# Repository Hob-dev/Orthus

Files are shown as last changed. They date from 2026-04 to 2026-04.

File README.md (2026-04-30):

# Orthus

An ergonomic split keyboard PCB with an integrated capacitive trackpad, Sharp Memory Display, and speaker. Designed around Kailh Choc low-profile switches and styled after Nothing.

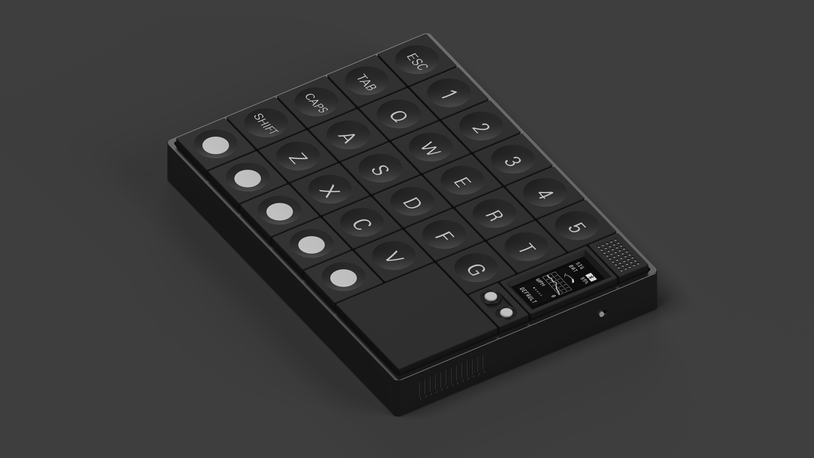
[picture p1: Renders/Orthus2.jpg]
Orthus iso render


## Overview

Orthus is a 6×5 ortholinear split — two mirrored halves, one with the alpha cluster (`QWERT`/`ASDFG`/`ZXCV`) and a number row (`1`–`5`), the other with the right-hand alphas, symbols, and a numpad row. Each half carries:

- 30 Kailh Choc keys (5 columns × 5 rows of alpha + outer modifier column + bottom-row arrow/macro circles)
- An integrated **OrthusTrackpad** capacitive sensor zone
- A **Sharp Memory Display** for live status (signal, battery, WPM, layer)
- Two side encoders / buttons next to the display
- A speaker grille

Both halves side-by-side:

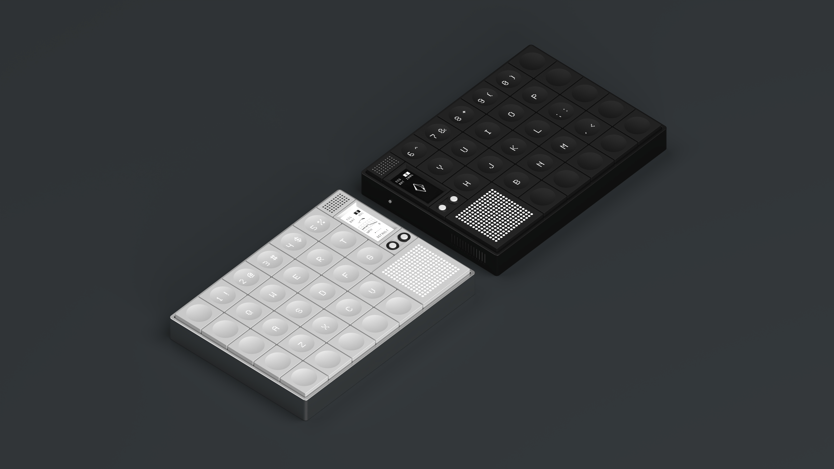
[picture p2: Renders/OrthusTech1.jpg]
Orthus split — both halves


Top-down view:

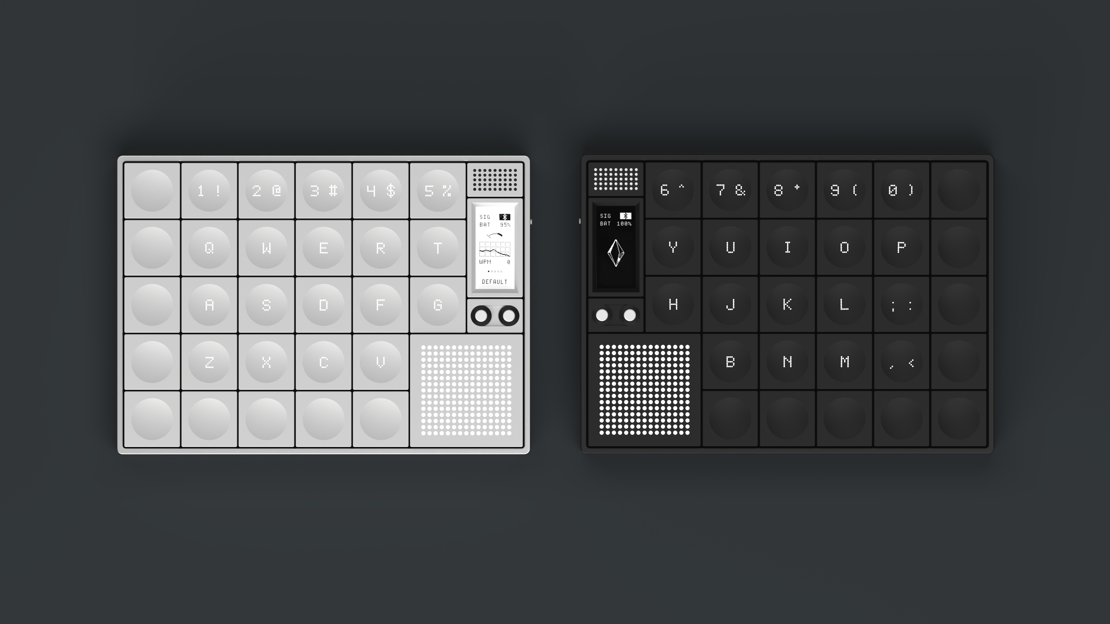
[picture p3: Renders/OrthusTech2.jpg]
Orthus top-down


## Status

**Functionally complete** — finishing touches remain before fabrication (see "Known gaps" below).

## Folder layout

```
Orthus/
├── KiCad/              Main KiCad 7+ project — open Orthus.kicad_pro
│   ├── Orthus.kicad_pcb        Main board layout
│   ├── Orthus.kicad_sch        Top-level schematic (loads sub-sheets)
│   ├── Left.kicad_sch          Left-half hierarchical sheet
│   ├── Right.kicad_sch         Right-half hierarchical sheet
│   ├── LeftMatrix.kicad_sch    Switch matrix sub-sheet
│   ├── OLED.kicad_sch          Display sub-sheet
│   ├── led.kicad_sch / led_r.kicad_sch   LED sub-sheets
│   ├── font/                   Custom silkscreen font SVGs (digits 0–9)
│   └── backups/                Dated KiCad auto-backups
├── Renders/            Project renders, layout studies, and WIP photos
├── 3D/                 Mechanical models — case, keycaps, trackpad
│   ├── Orthus.step / .stl / .gltf / .bin     Full assembly
│   ├── OrthusSimple*.step                    Simplified assembly variants
│   ├── OrthusKeycap*.step                    Keycap variants (Alt, TLBR, TRBL)
│   ├── AltarCap v2/v3.step                   Sculpted altar-style keycaps
│   ├── OrthusTrackpad*.step                  Trackpad PCB models
│   └── TM040YDHG32.step                      LCD reference model
├── Fabrication/        Trackpad grill cutouts (.dxf / .svg, square + slotted)
├── JLCPCB/             Empty — gerbers for the main PCB not yet generated
└── Components/
    ├── OrthusTrackpad/    Capacitive trackpad PCB (self-contained KiCad project + gerbers)
    └── OrthusSharp/       Sharp Memory Display breakout (KiCad project + gerbers)
```

## Components

| Component | Purpose | Status |
|---|---|---|
| **OrthusTrackpad** | Custom mutual-capacitance trackpad PCB integrated into each half. Self-contained KiCad project with its own JLCPCB gerber output. | Complete |
| **OrthusSharp** | Sharp Memory Display breakout, derived from an open-source `sharp_memory_display` design and significantly modified. KiCad 5 originals preserved under `Components/OrthusSharp/Legacy/`. | Complete |
| **OrthusMouseWheel** | Scroll wheel module — *not included in this repo, still under `Custom/Ergomania/OrthusMouseWheel/`.* | Unfinished |

## Alternative Renders

| | |
|---|---|
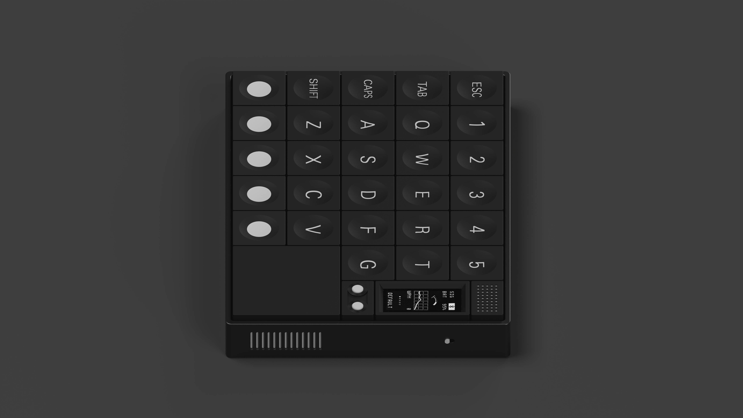
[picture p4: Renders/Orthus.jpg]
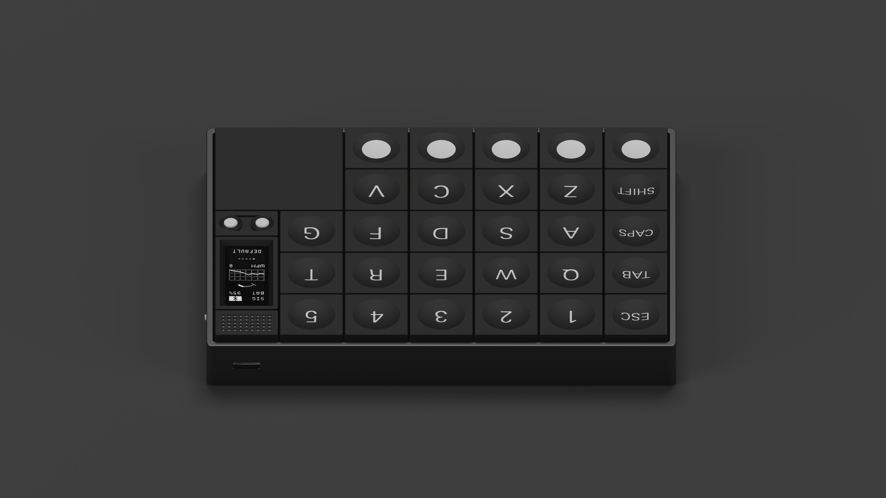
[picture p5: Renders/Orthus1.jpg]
|  |  |
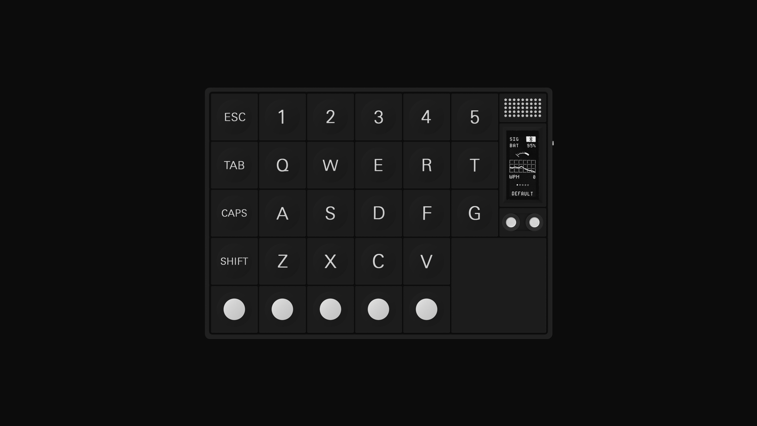
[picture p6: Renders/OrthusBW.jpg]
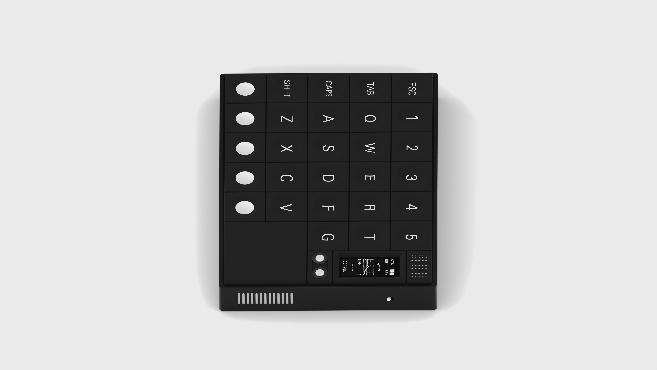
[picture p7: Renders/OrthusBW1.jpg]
|  |  |
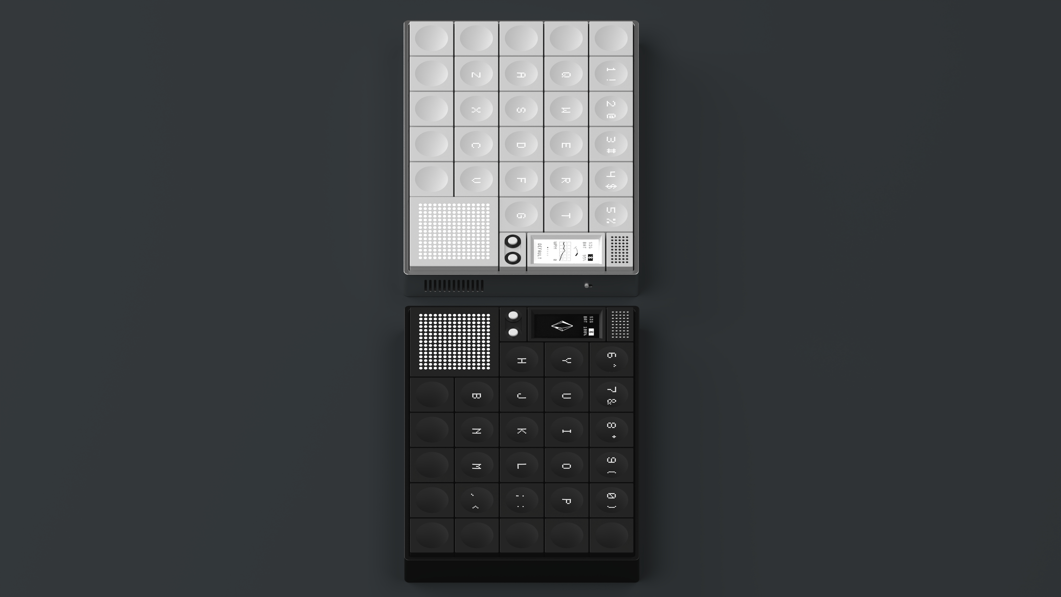
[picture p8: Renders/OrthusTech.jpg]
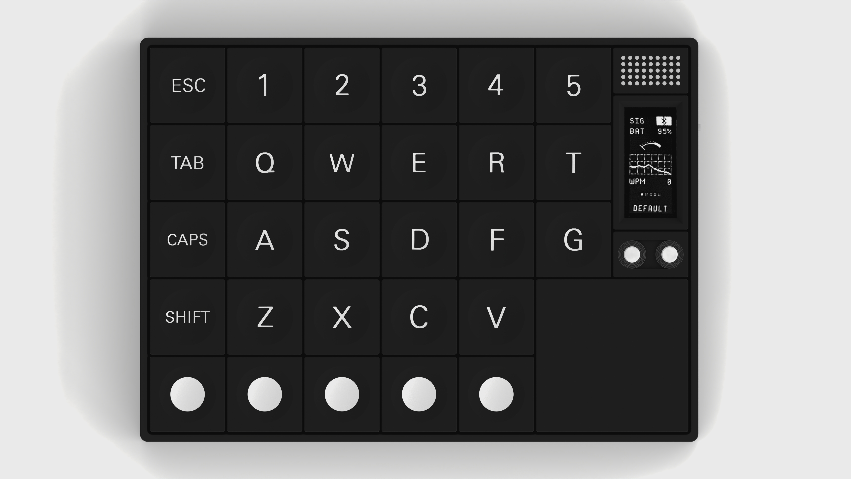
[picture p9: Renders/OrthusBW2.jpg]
|  |  |
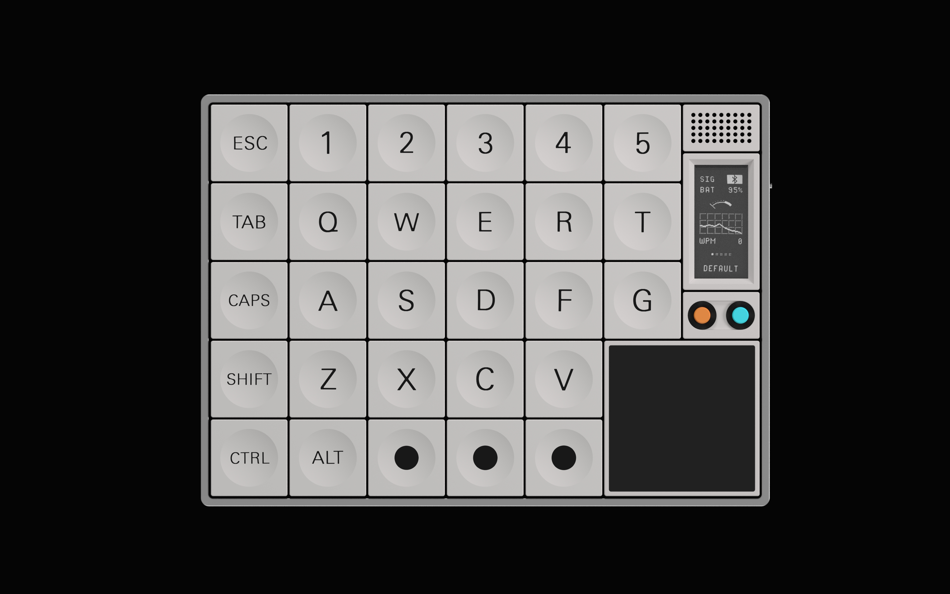
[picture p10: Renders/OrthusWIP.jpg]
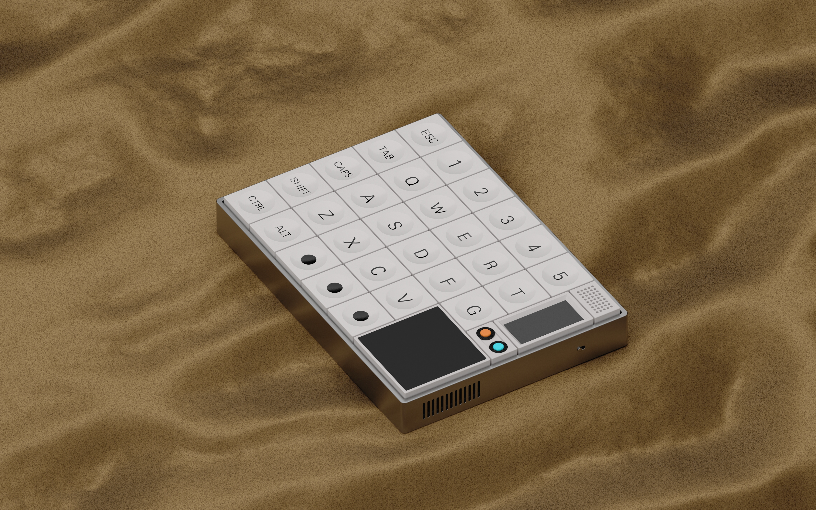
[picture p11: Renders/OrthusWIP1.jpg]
|  |  |

Layout studies and design exploration:

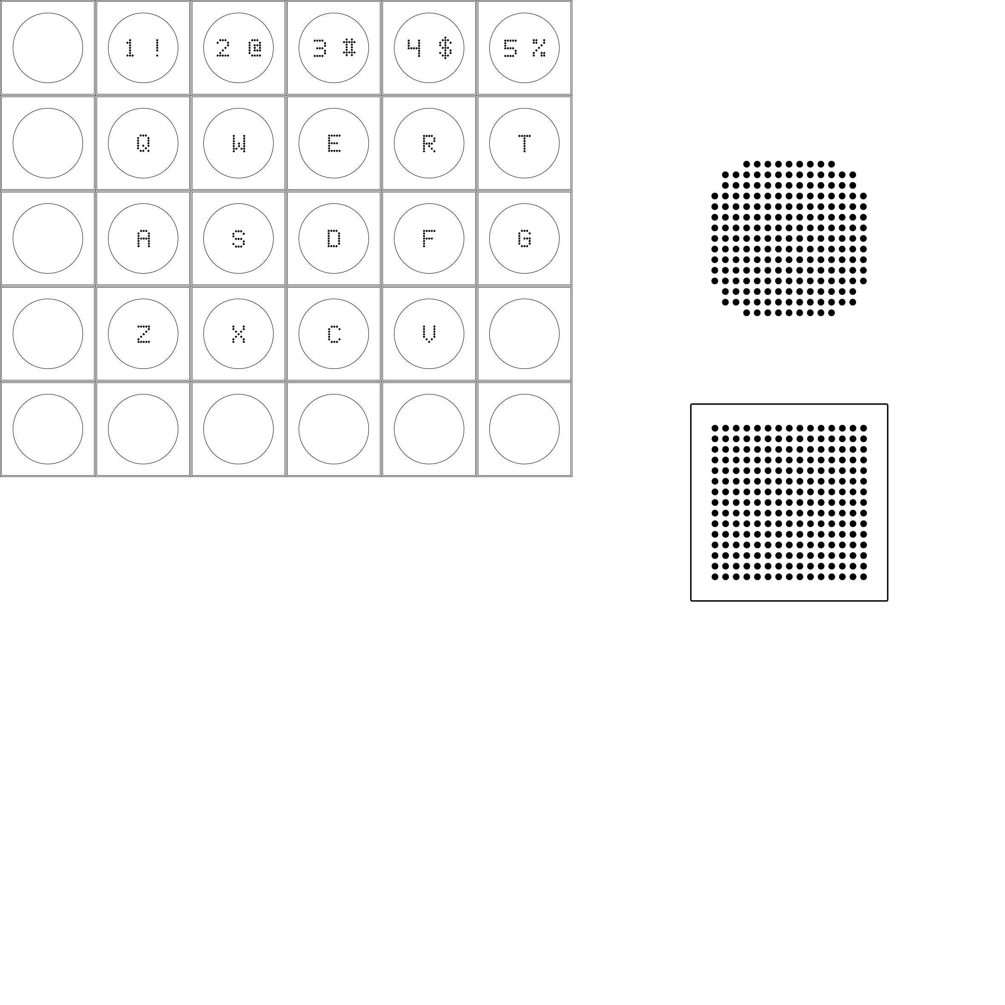
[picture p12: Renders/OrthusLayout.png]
Orthus layout study


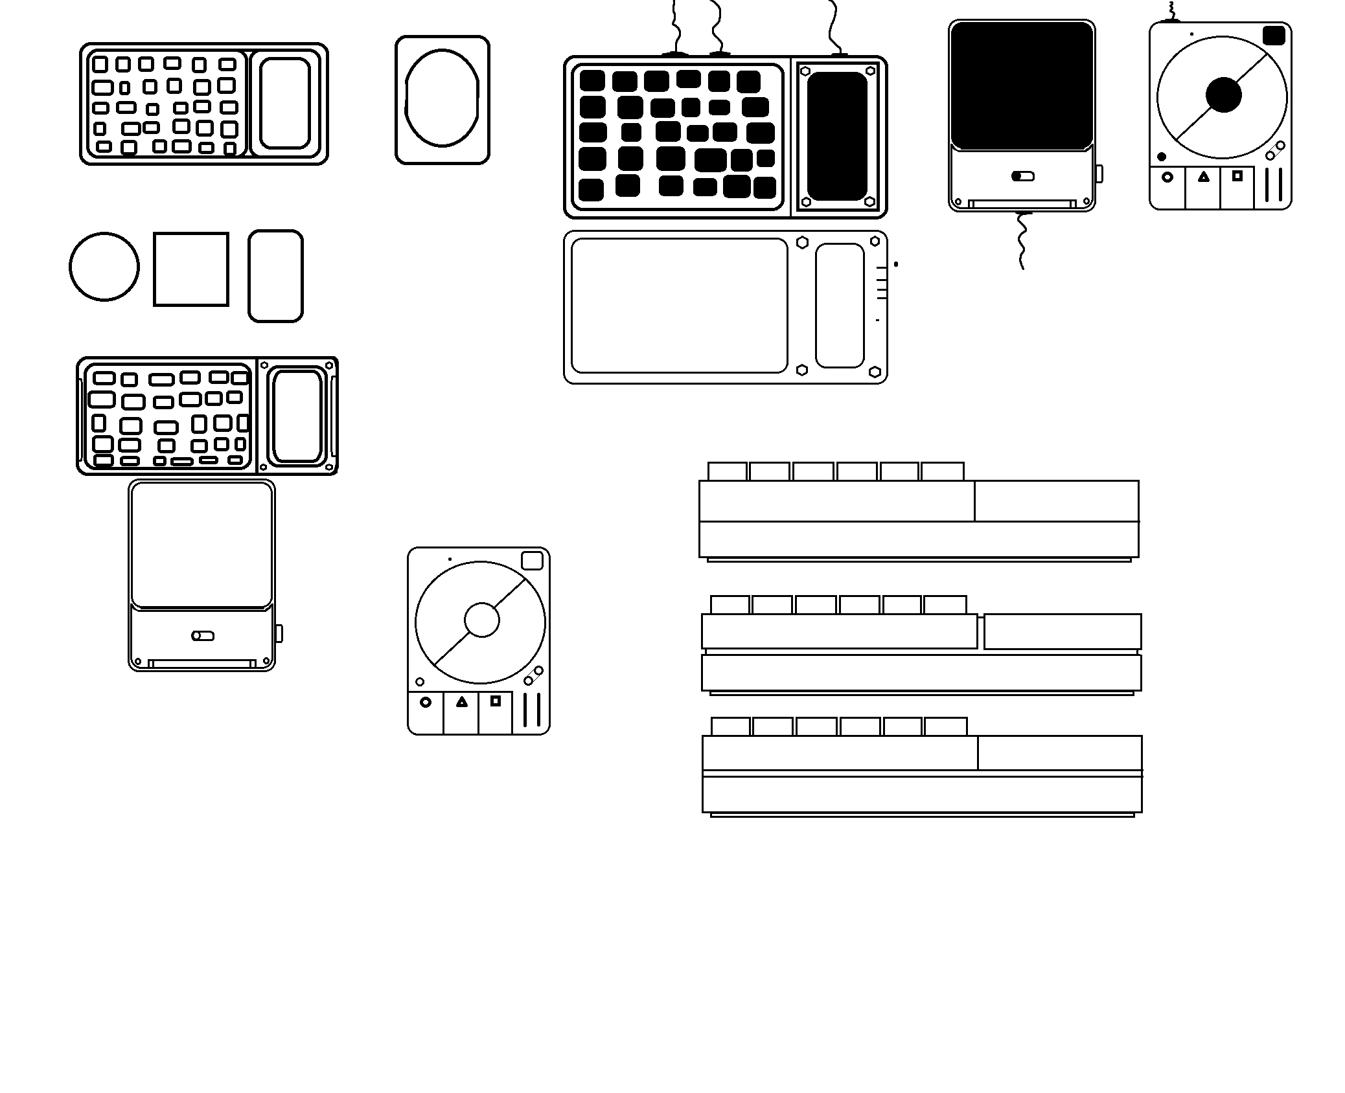
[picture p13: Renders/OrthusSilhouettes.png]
Form factor silhouettes


## Known gaps

- **No gerbers / JLCPCB order files** for the main Orthus PCB. `JLCPCB/` is an empty placeholder — gerbers need to be generated before fabrication.
- **No BOM / pick-and-place files** for the main PCB.
- **No assembly documentation** — refer to the hierarchical schematics under `KiCad/`.
- **3D model paths in `Orthus.kicad_pcb`** still reference absolute paths under `E:/EverythingKB/Custom/Ergomania/OrthusChoc/...`. The 3D viewer works locally because of this; for an open-source release these should be repointed at `Orthus/3D/`.
- **3D model path in `OrthusSharp.kicad_pro`** uses `../../Custom/Ergomania/test/OrthusSharp.step` (relative to its old location).
- **OrthusSharp `fp-lib-table`** carries hardcoded macOS paths (`/Users/karnadi/...`) inherited from the upstream fork — regenerate or repoint to your local KiCad libraries on first open.

## Attribution

`Components/OrthusSharp/` is derived from an open-source Sharp Memory Display breakout (see `Components/OrthusSharp/LICENSE`). Heavily modified for integration with Orthus.

## License

Orthus is licensed under the [Creative Commons Attribution-NonCommercial 4.0 International License (CC BY-NC 4.0)](https://creativecommons.org/licenses/by-nc/4.0/).

`Components/OrthusSharp/` is third-party and retains its original license — see [`Components/OrthusSharp/LICENSE`](Components/OrthusSharp/LICENSE).

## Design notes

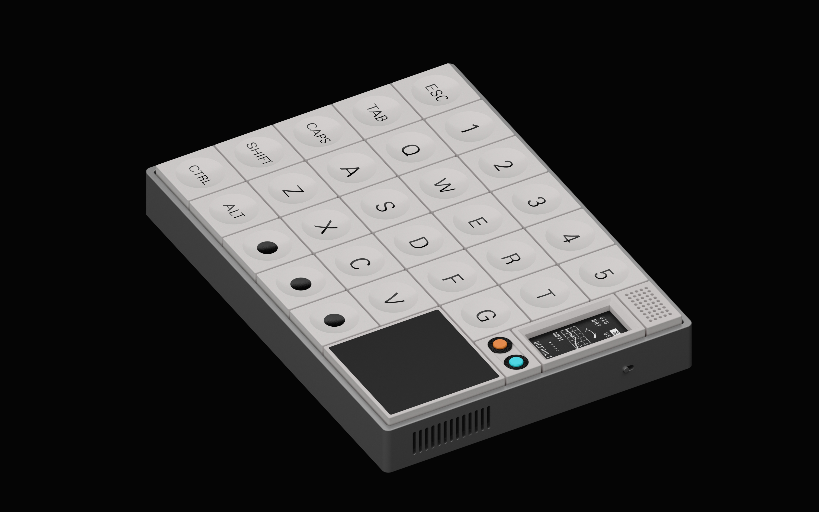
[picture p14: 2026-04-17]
Renders/OrthusWIP2.jpg

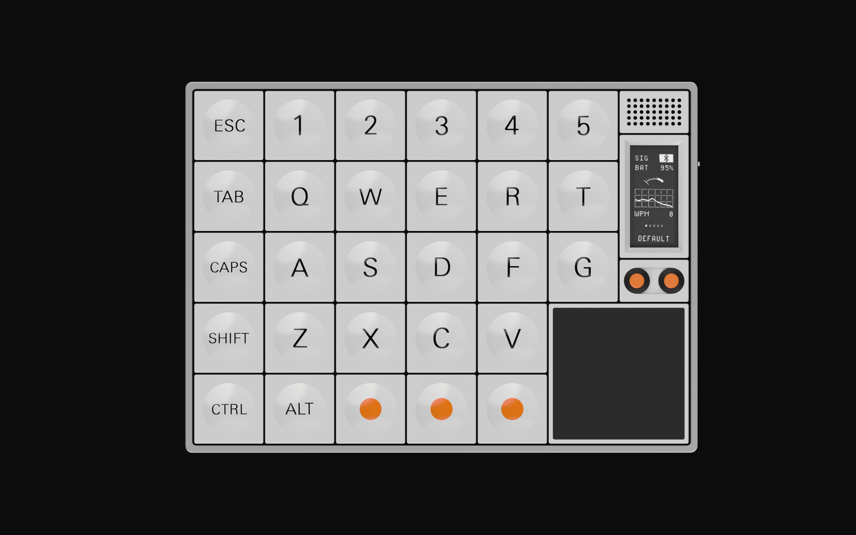
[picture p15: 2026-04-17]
Renders/OrthusWIP6.jpg

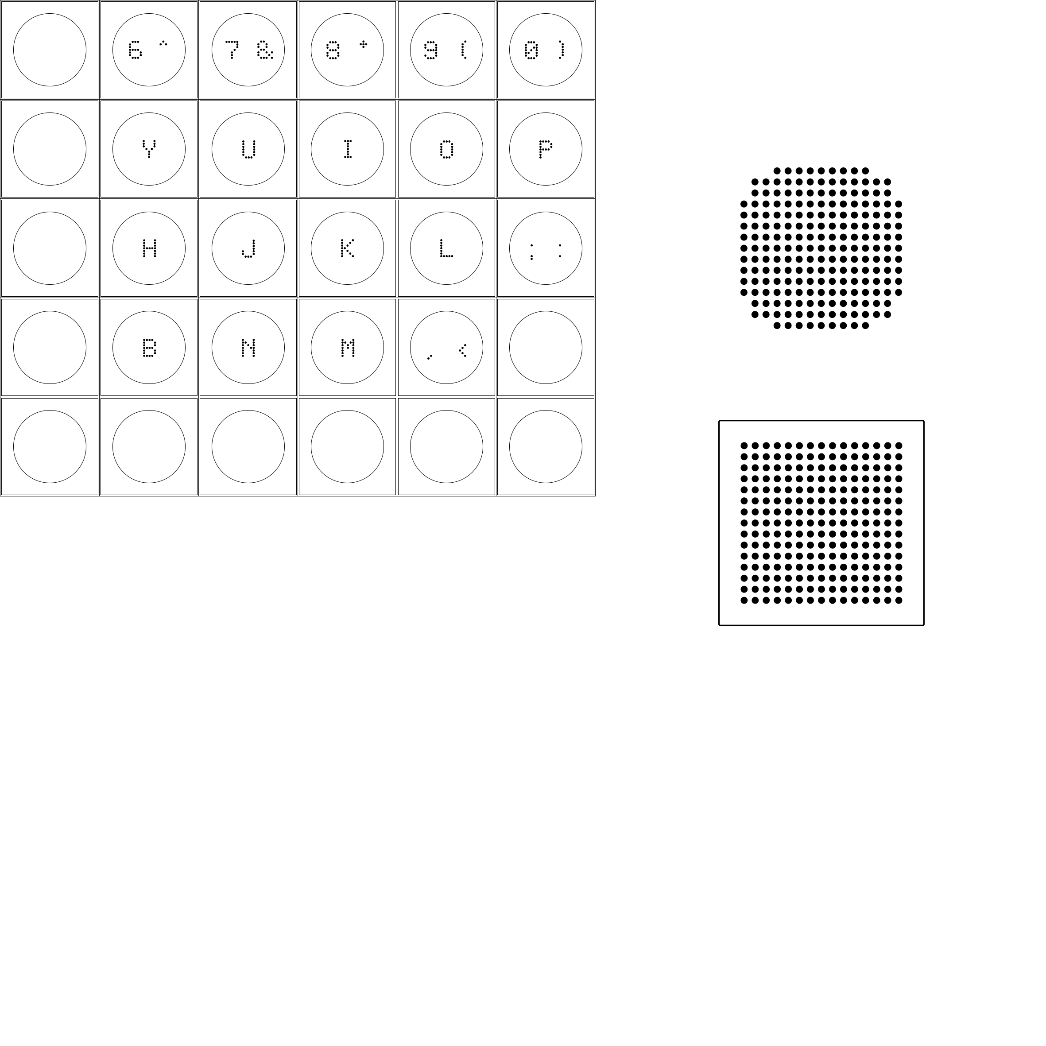
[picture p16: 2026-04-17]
Renders/OrthusLayout1.png

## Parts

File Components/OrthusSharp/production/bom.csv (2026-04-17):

Comment | Designator | Footprint | LCSC Part #
560pF/680pF Unpolarized capacitor, small symbol | C1 | C_0603_1608Metric_Pad1.08x0.95mm_HandSolder | C84721
1uF Unpolarized capacitor, small symbol | C2 | C_0603_1608Metric_Pad1.08x0.95mm_HandSolder | C15849
1uF Unpolarized capacitor, small symbol | C3 | C_0603_1608Metric_Pad1.08x0.95mm_HandSolder | C15849
Ferrite_Bead_Small | FB1,FB2 | R_0805_2012Metric_Pad1.20x1.40mm_HandSolder | C1017
MountingHole Mounting Hole without connection | H1,H2,H3,H4 | MountingHole_2.2mm_M2_DIN965_Pad
Conn_01x05 Generic connector, single row, 01x05, script generated (kicad-library-utils/schlib/autogen/connector/) | J1 | PinSocket_1x05_P2.54mm_Vertical
Conn_01x10 Generic connector, single row, 01x10, script generated (kicad-library-utils/schlib/autogen/connector/) | J2,J4 | Hirose_FH12-10S-0.5SH_1x10-1MP_P0.50mm_Horizontal | C506791
Conn_01x05_Male Generic connector, single row, 01x05, script generated (kicad-library-utils/schlib/autogen/connector/) | J3 | JST_SH_SM05B-SRSS-TB_1x05-1MP_P1.00mm_Horizontal
10k Resistor, small symbol | R1,R2,R3 | R_0603_1608Metric_Pad0.98x0.95mm_HandSolder | C25804

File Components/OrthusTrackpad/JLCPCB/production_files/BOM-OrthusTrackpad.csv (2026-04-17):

Comment | Designator | Footprint | LCSC | Quantity
100nF | C7 | C_0402_1005Metric | C1525 | 1
100pF | C1,C3,C5 | C_0402_1005Metric | C1546 | 3
IQS7211E001QNR | U1 | UQFN-20_L3.0-W3.0-P0.40-BL-EP1.7 | C20179547 | 1
4.7k | R1,R2,R3 | R_0603_1608Metric | C23162 | 3
Conn_01x06 | J1 | FPC-SMD_6P-P0.50_XUNPU_FPC-05F-6PH15 | C2856814 | 1
2.2uF | C2,C4,C6 | C_0402_1005Metric | C60078 | 3

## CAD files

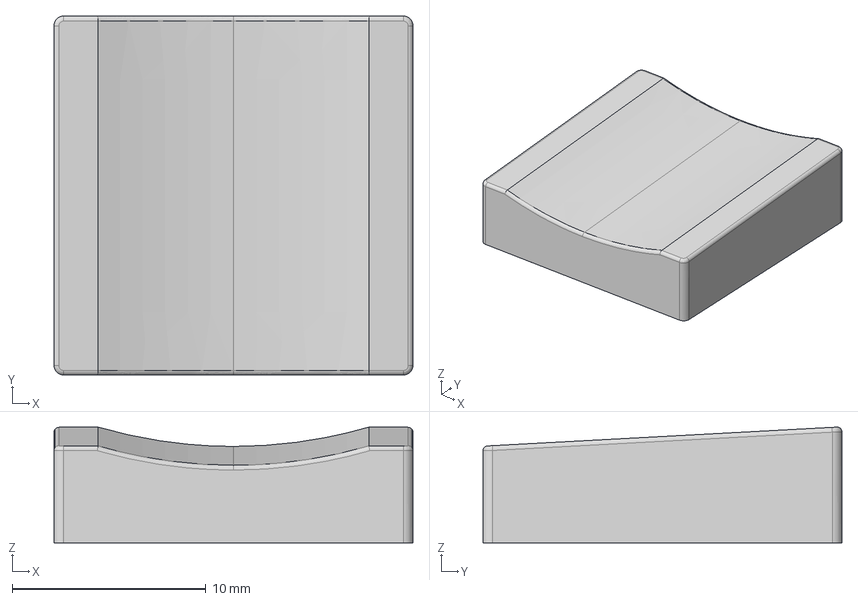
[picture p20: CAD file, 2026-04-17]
3D/OrthusKeycapAlt.step
18.5 x 18.5 x 5.99 mm

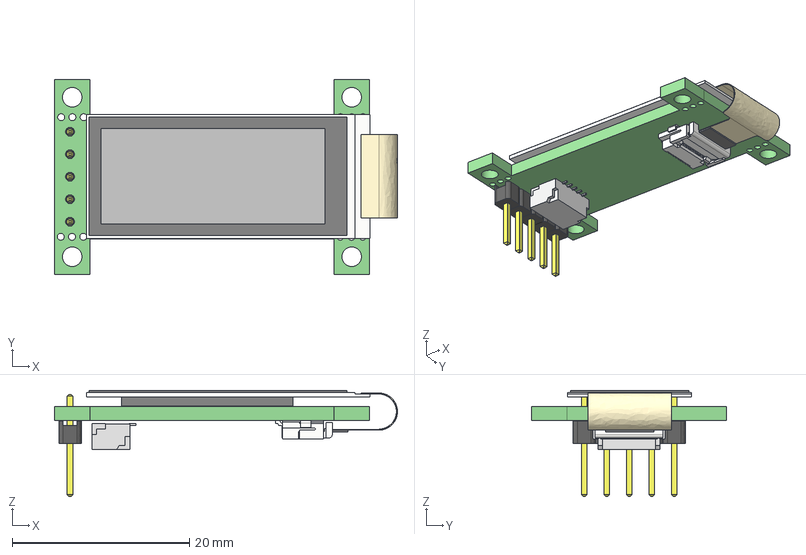
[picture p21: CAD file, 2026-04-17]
Components/OrthusSharp/OrthusSharp.step
38.7 x 22.0 x 12.0 mm
sharp_memory_display PCB

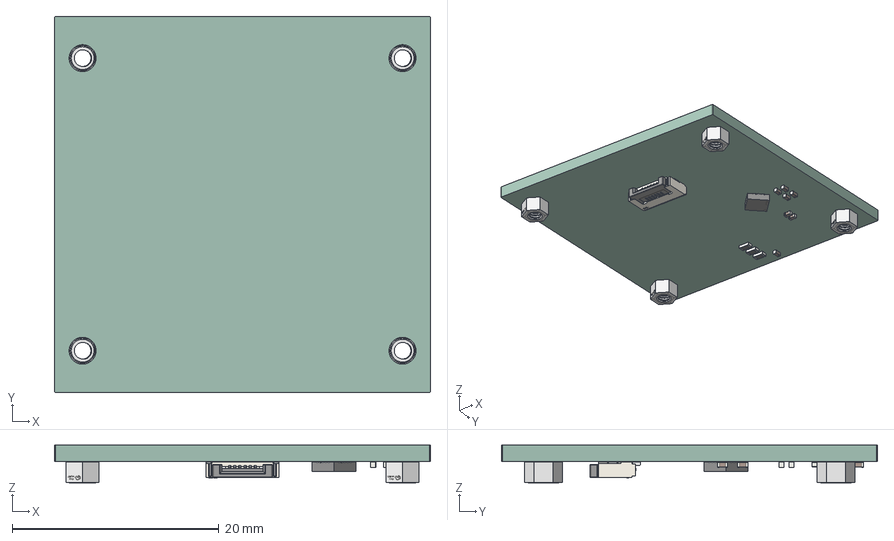
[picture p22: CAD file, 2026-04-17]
Components/OrthusTrackpad/3D/OrthusTrackpad.step
36.4 x 36.4 x 3.65 mm
C_0402_1005Metric x 7
SMD-1_SMTSO1620MTJ x 4
R_0603_1608Metric x 3
UQFN-20_L3.0-W3.0-P0.40-BL-EP1.7
FPC-SMD_6P-P0.50_XUNPU_FPC-05F-6PH15
OrthusTrackpad_PCB

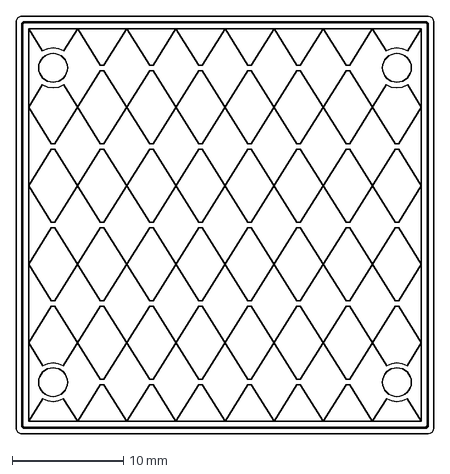
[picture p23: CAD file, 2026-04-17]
Components/OrthusTrackpad/Fabrication/MutualCapSensorGride.dxf
37.6 x 37.6 mm

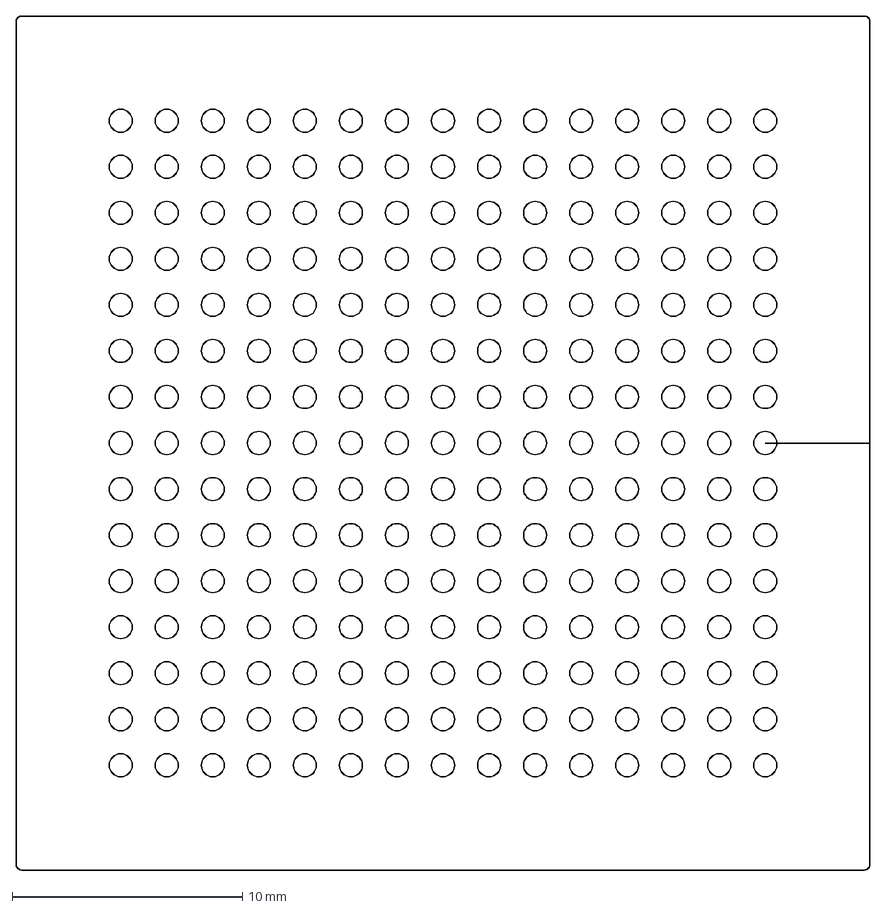
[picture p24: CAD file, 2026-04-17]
Fabrication/TrackpradGrillsSquare.dxf
37.1 x 37.1 mm

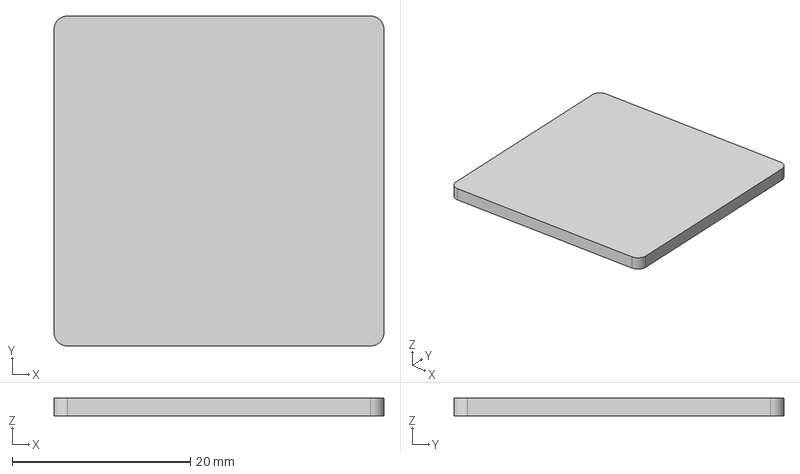
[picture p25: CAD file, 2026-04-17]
3D/OrthusTrackpad3D.step
37.0 x 37.0 x 2.00 mm

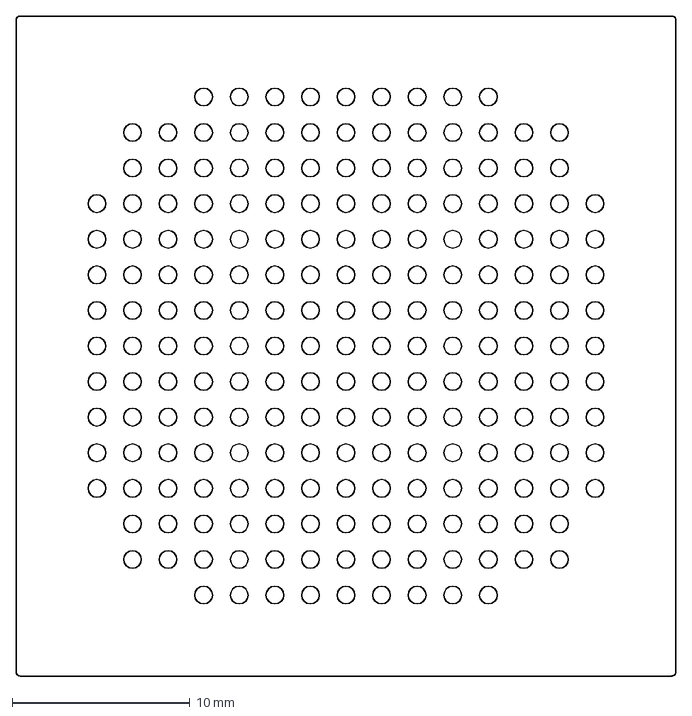
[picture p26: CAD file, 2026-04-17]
Fabrication/TrackpradGrills.dxf
37.1 x 37.1 mm

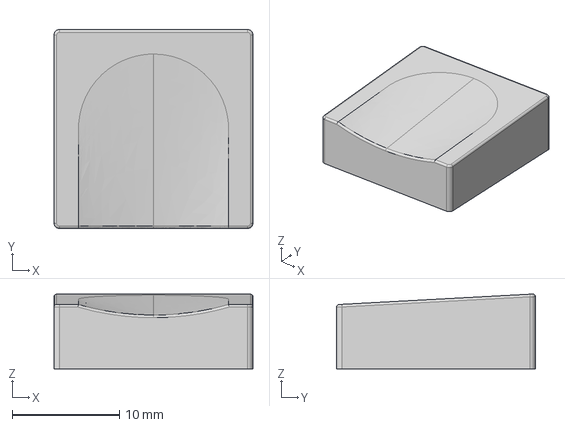
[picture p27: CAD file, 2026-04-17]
3D/OrthusKeycapAlt1.step
18.5 x 18.5 x 6.99 mm

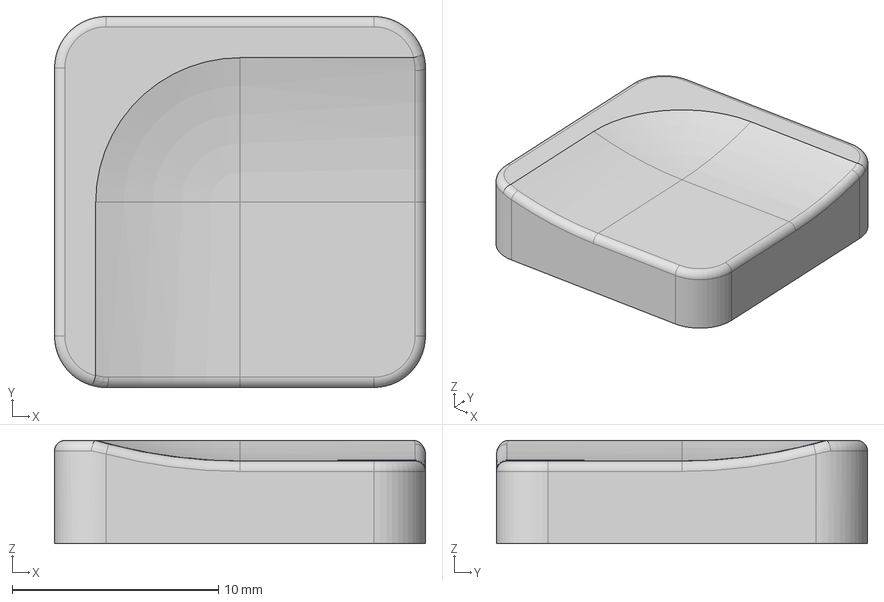
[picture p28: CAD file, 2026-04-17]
3D/OrthusKeycapAltTLBR.step
18.0 x 18.0 x 5.00 mm

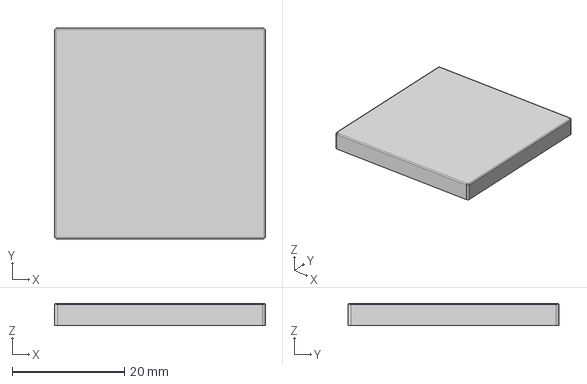
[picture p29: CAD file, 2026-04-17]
3D/OrthusTrackpad v31.step
37.6 x 37.6 x 4.00 mm

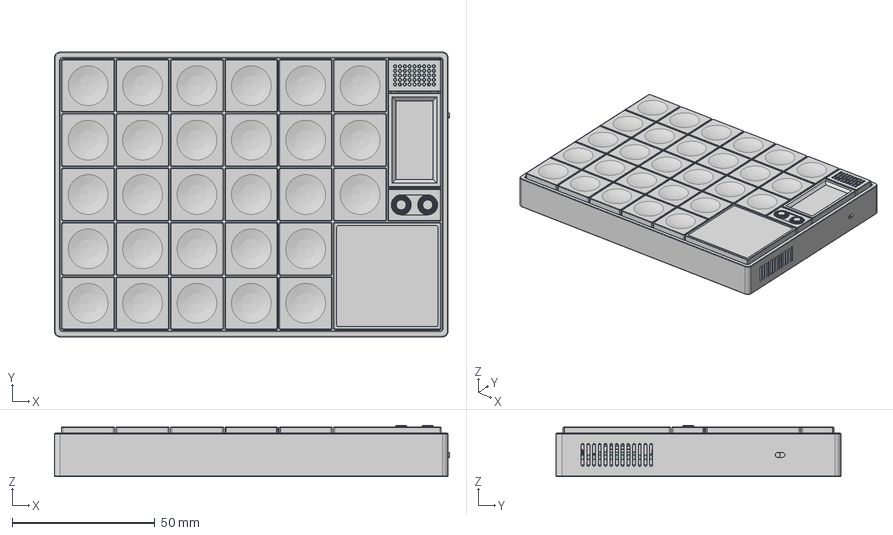
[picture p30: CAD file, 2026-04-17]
3D/Orthus.step
138.3 x 99.8 x 17.9 mm
C_0402_1005Metric_1 x 10
SMD-1_SMTSO1620MTJ_1 x 4
R_0402_1005Metric_1 x 14
Fuse_0603_1608Metric_1
SOT_23
CON_TYPE-C-31-M-14 v3
DFN_8_1EP_2x2mm_P05mm_EP07x13mm
SOT_23_6 x 3
FPC-SMD_8P-P0.50_XUNPU_FPC-05F-8PH15_1
L_0402_1005Metric_1
MSK12C02 v4
ebyte_E73-2G4M08S1C v2
FPC-SMD_6P-P0.50_XUNPU_FPC-05F-6PH15_1
L_0603_1608Metric_1
SW-SMD_4P-L5.1-W5.1-P3.70-LS6.5-TL_H1.5_1
HS_Kailh_Choc v4 x 28
OrthusKeycap v6 x 28
D_SOD_123 x 28
SMD_BD5.6-L5.6-W5.6-D3.6_1 x 5
CON_781710002 v4
_autosave-test_PCB
SW-SMD_4P-L5.1-W5.1-P3.70-LS6.5-TL_H3.5_2 x 2
R_0805_2012Metric_2 x 2
R_0603_1608Metric_3 x 3
FPC-SMD_8P-P0.50_XUNPU_FPC-05F-8PH15_3
C_0603_1608Metric_3 x 3
FPC-SMD_10P-P0.50_XUNPU_FPC-05F-10PH15_1
SMD-1_SMTSO1620MTJ_6 x 4
sharp_memory_display_PCB
OrthusTrackpad

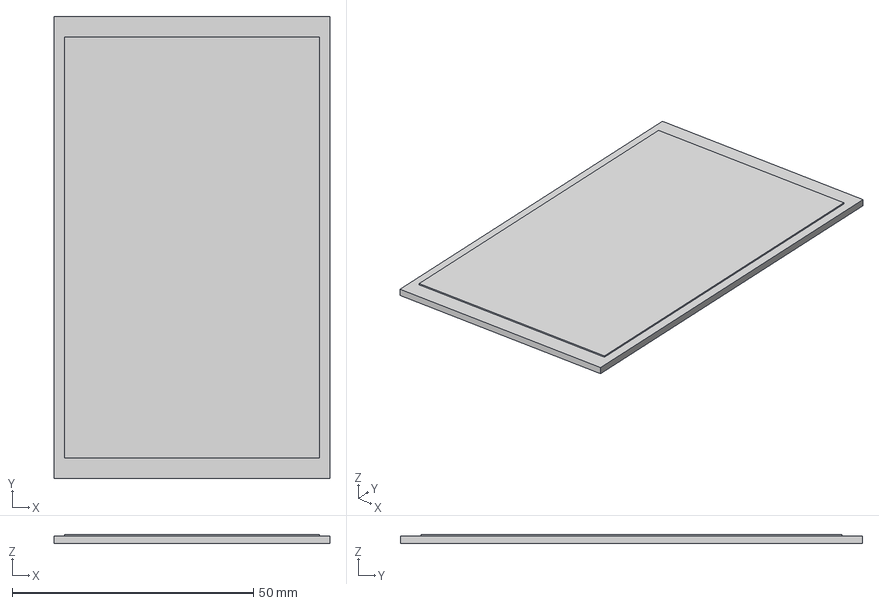
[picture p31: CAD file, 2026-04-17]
3D/TM040YDHG32.step
57.2 x 95.8 x 1.93 mm

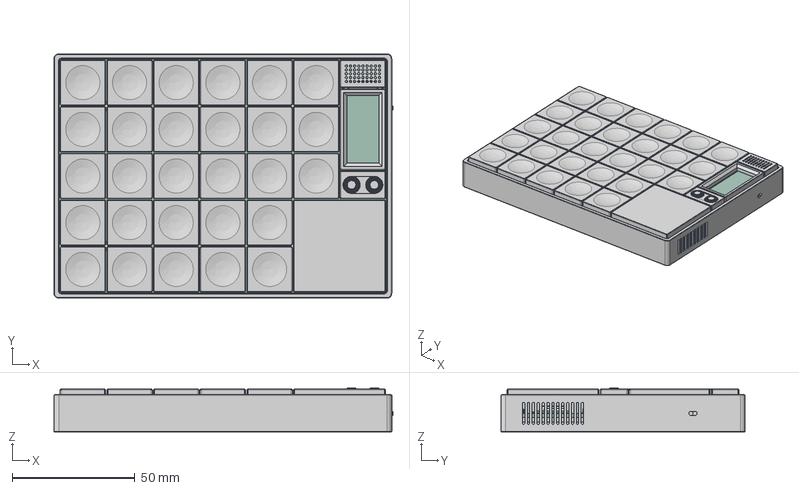
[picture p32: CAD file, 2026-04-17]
3D/OrthusSimple.step
138.3 x 99.8 x 17.9 mm
OrthusTrackpad1
C_0402_1005Metric_1 x 10
SMD-1_SMTSO1620MTJ_1 x 4
R_0402_1005Metric_1 x 14
Fuse_0603_1608Metric_1
SOT_23
CON_TYPE-C-31-M-14 v3
DFN_8_1EP_2x2mm_P05mm_EP07x13mm
SOT_23_6 x 3
FPC-SMD_8P-P0.50_XUNPU_FPC-05F-8PH15_1
L_0402_1005Metric_1
MSK12C02 v4
ebyte_E73-2G4M08S1C v2
FPC-SMD_6P-P0.50_XUNPU_FPC-05F-6PH15_1
L_0603_1608Metric_1
SW-SMD_4P-L5.1-W5.1-P3.70-LS6.5-TL_H1.5_1
HS_Kailh_Choc v4 x 28
OrthusKeycap v6 x 28
D_SOD_123 x 28
SMD_BD5.6-L5.6-W5.6-D3.6_1 x 5
CON_781710002 v4
_autosave-test_PCB
SW-SMD_4P-L5.1-W5.1-P3.70-LS6.5-TL_H3.5_2 x 2
R_0805_2012Metric_2 x 2
R_0603_1608Metric_3 x 3
FPC-SMD_8P-P0.50_XUNPU_FPC-05F-8PH15_3
C_0603_1608Metric_3 x 3
FPC-SMD_10P-P0.50_XUNPU_FPC-05F-10PH15_1
SMD-1_SMTSO1620MTJ_6 x 4
sharp_memory_display_PCB

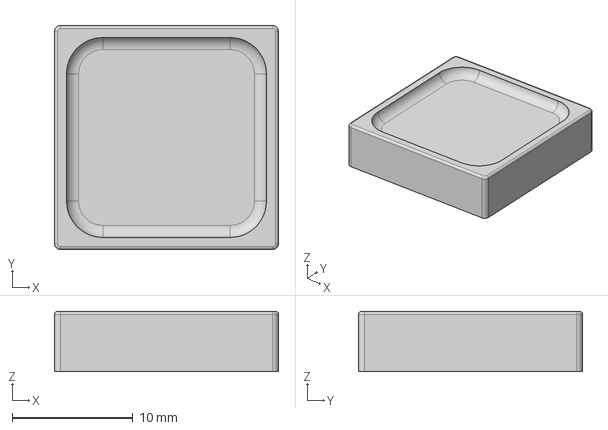
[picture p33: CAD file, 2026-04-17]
3D/OrthusKeycap.step
18.6 x 18.6 x 5.00 mm

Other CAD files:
3D/OrthusKeycapAltTRBL.step
3D/AltarCap v3.step
3D/AltarCap v2.step

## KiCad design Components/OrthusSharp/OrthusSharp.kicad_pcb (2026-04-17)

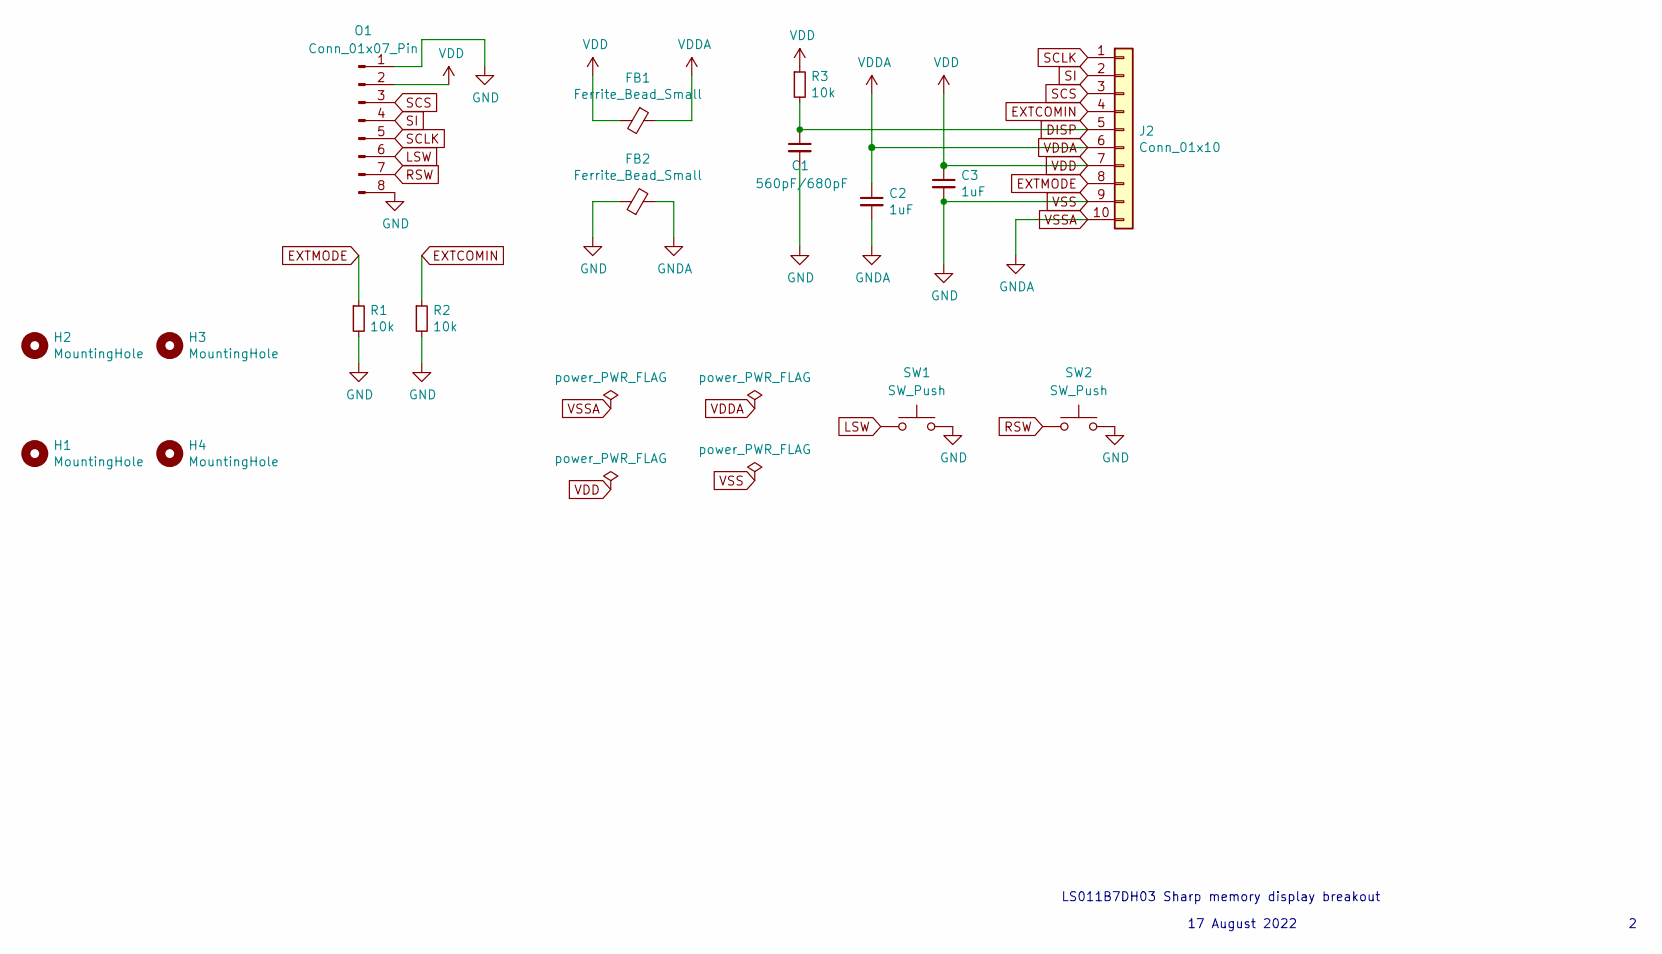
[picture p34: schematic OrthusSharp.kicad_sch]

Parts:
C1: 560pF/680pF; C_0603_1608Metric_Pad1.08x0.95mm_HandSolder; LCSC C84721
C2, C3: 1uF; C_0603_1608Metric_Pad1.08x0.95mm_HandSolder; LCSC C15849
FB1, FB2: Ferrite_Bead_Small; R_0805_2012Metric_Pad1.20x1.40mm_HandSolder; LCSC C1017
H1, H2, H3, H4: MountingHole; SMD-1_SMTSO1620MTJ
J2: Conn_01x10; FPC-SMD_10P-P0.50_XUNPU_FPC-05F-10PH15; LCSC C506791
O1: Conn_01x07_Pin; FPC-SMD_8P-P0.50_XUNPU_FPC-05F-8PH15
R1, R2, R3: 10k; R_0603_1608Metric_Pad0.98x0.95mm_HandSolder; LCSC C25804
SW1, SW2: SW_Push; SW-SMD_4P-L5.1-W5.1-P3.70-LS6.5-TL_H3.5

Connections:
DISP: C1.1, J2.5, R3.2
EXTCOMIN: J2.4, R2.1
EXTMODE: J2.8, R1.1
LSW: O1.6, SW1.1
RSW: O1.7, SW2.1
SCLK: J2.1, O1.5
SCS: J2.3, O1.3
SI: J2.2, O1.4
VDD: C3.1, FB1.2, J2.7, O1.2, R3.1
VDDA: C2.1, FB1.1, J2.6
VSS: C1.2, C3.2, FB2.1, J2.9, O1.1, O1.8, R1.2, R2.2, SW1.2, SW2.2
VSSA: C2.2, FB2.2, J2.10

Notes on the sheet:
17 August 2022
LS011B7DH03 Sharp memory display breakout

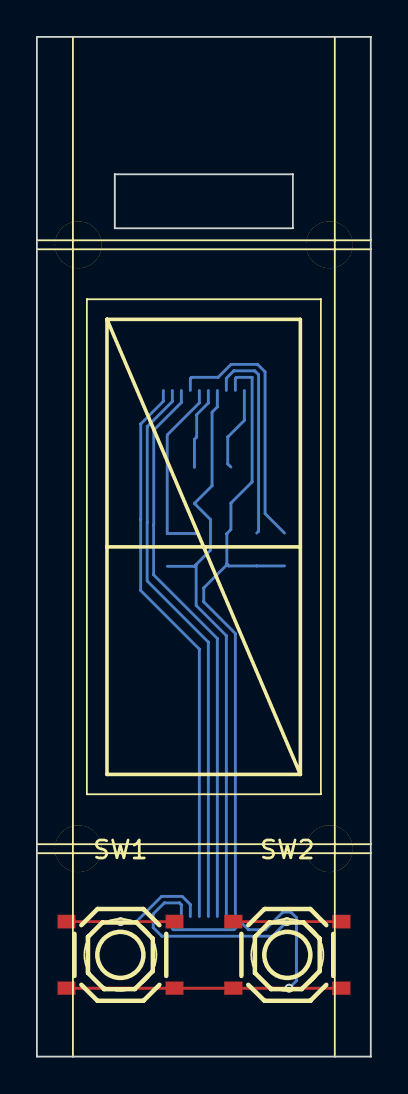
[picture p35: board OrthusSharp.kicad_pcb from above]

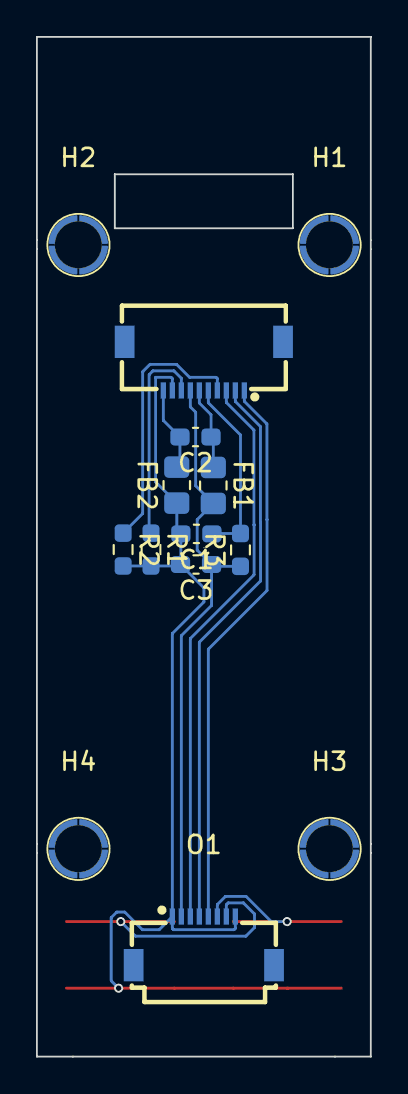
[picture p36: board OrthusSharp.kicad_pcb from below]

Board: 2 copper layers, 18.6 x 56.6 mm, 16 parts (14 on the bottom side), 12 nets.

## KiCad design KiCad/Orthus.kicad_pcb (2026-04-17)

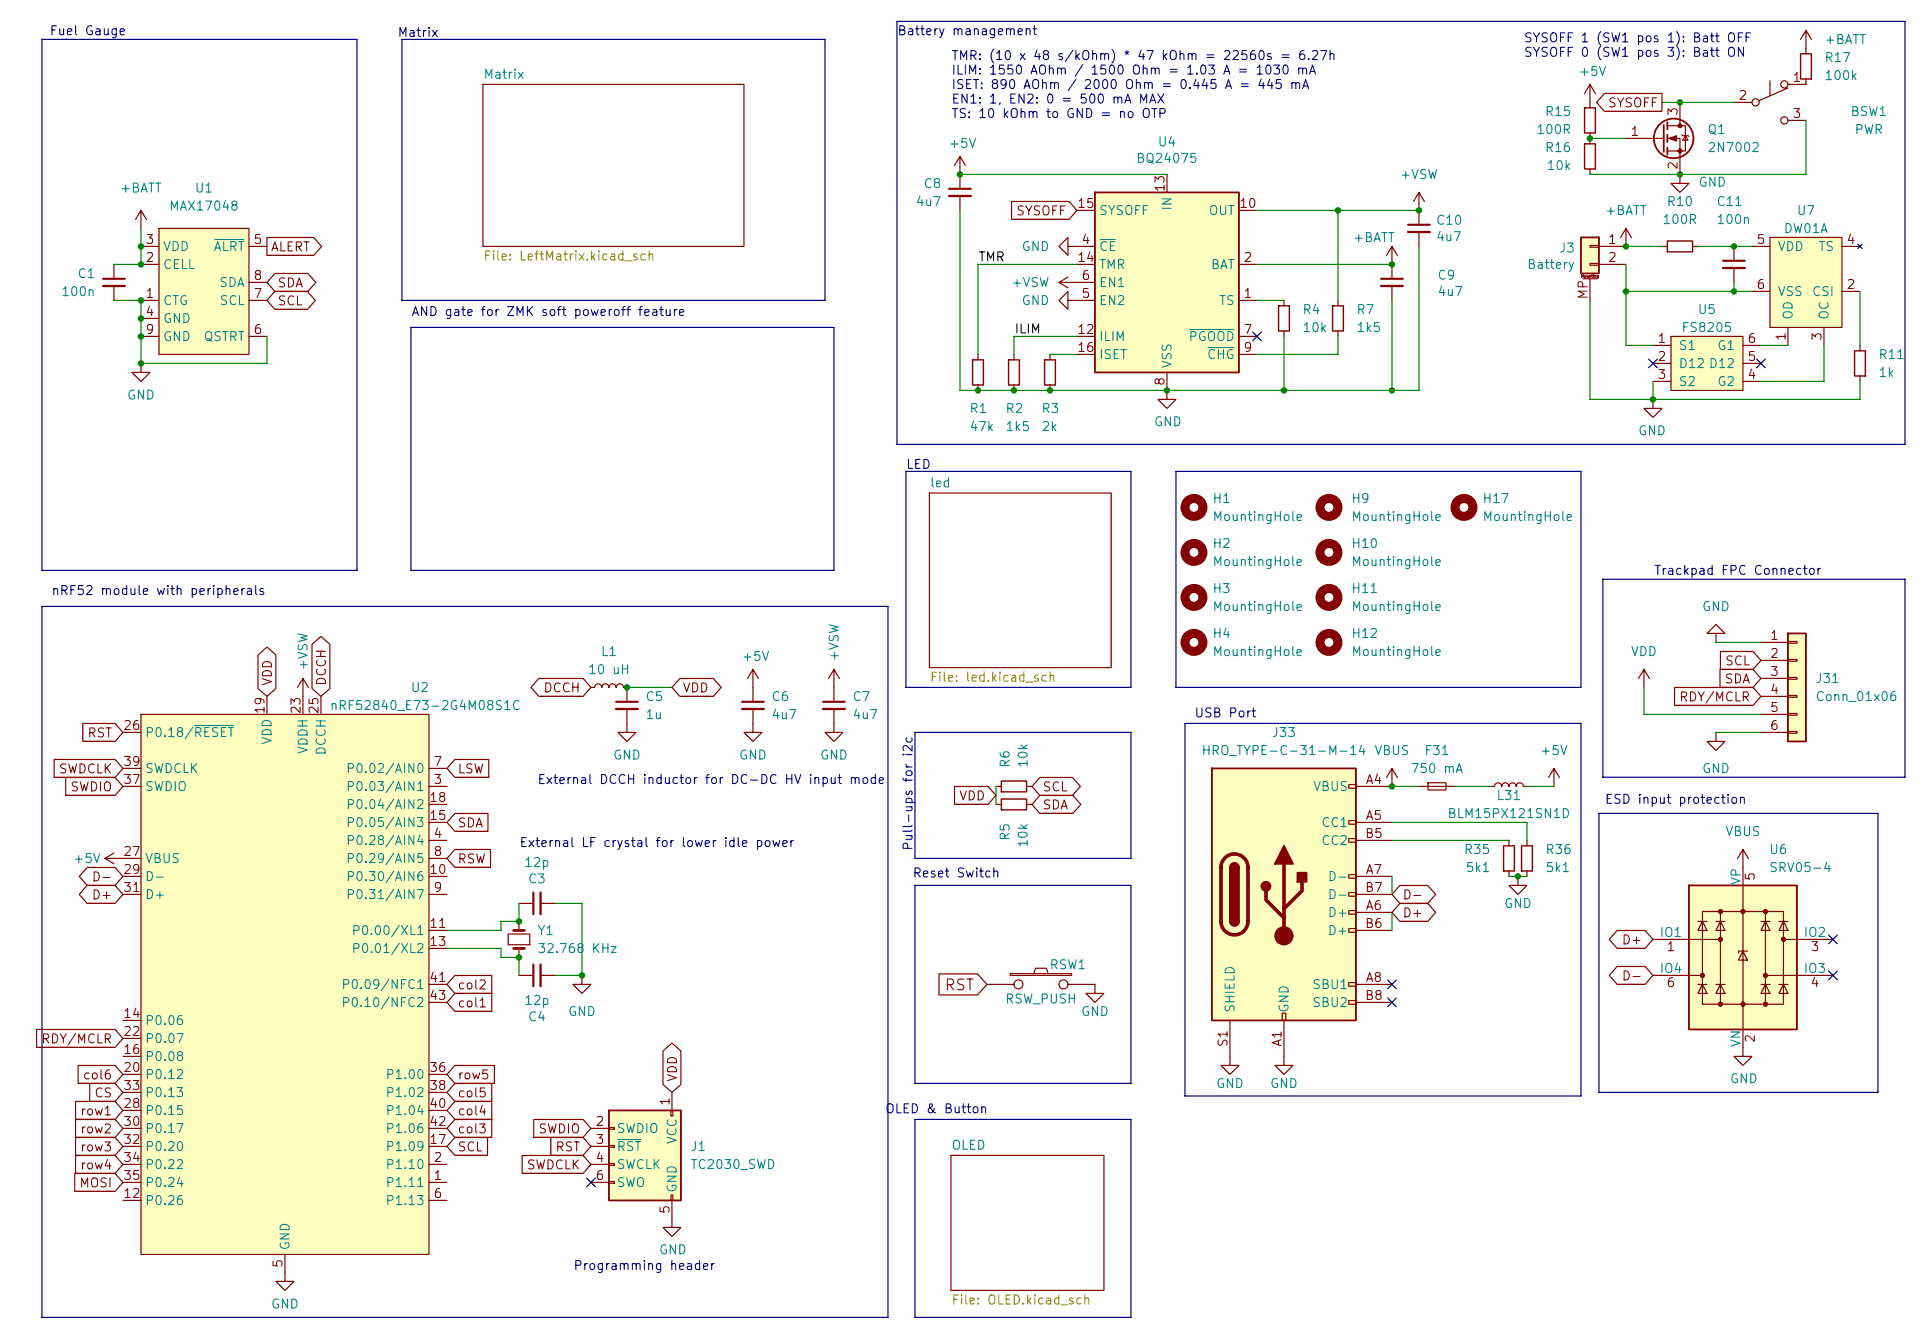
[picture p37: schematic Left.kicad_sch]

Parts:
BSW1: PWR; SW_MSK12C02-HB
C1: 100n; C_0402_1005Metric; LCSC C307331
C3, C4: 12p; C_0402_1005Metric; LCSC C1547
C5: 1u; C_0402_1005Metric; LCSC C52923
C6, C7: 4u7; C_0402_1005Metric; LCSC C23733
C8, C9, C10: 4u7; C_0402_1005Metric
C11: 100n; C_0402_1005Metric
F31: 750 mA; Fuse_0603_1608Metric
H1, H2, H3, H4: MountingHole; SMD-1_SMTSO1620MTJ
H9, H10, H11, H12, H17: MountingHole; SMD_BD5.6-L5.6-W5.6-D3.6
J1: TC2030_SWD; CON_TC2030_outlined
J3: Battery; Molex_Pico-EZmate_78171-0002_1x02-1MP_P1.20mm_Vertical; LCSC C505023
J31: Conn_01x06; FPC-SMD_6P-P0.50_XUNPU_FPC-05F-6PH15
J33: HRO_TYPE-C-31-M-14; USB_C_Receptacle_HRO_TYPE-C-31-M-14
L1: 10 uH; L_0603_1608Metric; LCSC C92982
L31: BLM15PX121SN1D; L_0402_1005Metric
Q1: 2N7002; SOT-23
R1: 47k; R_0402_1005Metric
R2, R7: 1k5; R_0402_1005Metric
R3: 2k; R_0402_1005Metric
R4, R16: 10k; R_0402_1005Metric
R5, R6: 10k; R_0402_1005Metric; LCSC C25744
R10, R15: 100R; R_0402_1005Metric
R11: 1k; R_0402_1005Metric
R17: 100k; R_0402_1005Metric
R35, R36: 5k1; R_0402_1005Metric
RSW1: RSW_PUSH; SW-SMD_4P-L5.1-W5.1-P3.70-LS6.5-TL_H1.5
U1: MAX17048; DFN-8-1EP_2x2mm_P0.5mm_EP0.6x1.2mm; LCSC C2682616
U2: nRF52840_E73-2G4M08S1C; LCSC C356849
U4: BQ24075; VQFN-16-1EP_3x3mm_P0.5mm_EP1.6x1.6mm
U5: FS8205; SOT-23-6; LCSC C32254
U6: SRV05-4; SOT-23-6-routable; LCSC C7420376
U7: DW01A; SOT-23-6; LCSC C61503
Y1: 32.768 KHz; Crystal_SMD_2012-2Pin_2.0x1.2mm; LCSC C55208

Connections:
+5V: C6.1, C8.1, L31.2, R15.1, U2.27 (VBUS), U4.13 (IN)
+BATT: C1.1, C9.1, J3.1, R10.1, R17.2, U1.2 (CELL), U1.3 (VDD), U4.2 (BAT), U4.3 (BAT)
+VSW: C7.1, C10.1, R7.1, U2.23 (VDDH), U4.6 (EN1), U4.10 (OUT), U4.11 (OUT); also elsewhere on the board
/Left/ILIM: R2.1, U4.12 (ILIM)
/Left/TMR: R1.1, U4.14 (TMR)
ALERT: U1.5 (~ALRT)
CS: U2.33 (P0.13); also elsewhere on the board
D+: J33.A6 (D+), J33.B6 (D+), U2.31 (D+), U6.1 (IO1)
D-: J33.A7 (D-), J33.B7 (D-), U2.29 (D-), U6.6 (IO4)
DCCH: L1.1, U2.25 (DCCH)
GND: BSW1.3 (C), C1.2, C3.2, C4.2, C5.2, C6.2, C7.2, C8.2, C9.2, C10.2, J1.5 (GND), J3.MP (MountPin), J31.1, J31.6, J33.A1 (GND), J33.A12 (GND), J33.B1 (GND), J33.B12 (GND), J33.S1 (SHIELD), Q1.2 (S), R1.2, R2.2, R3.2, R4.2, R11.1, R16.2, R35.1, R36.1, RSW1.2, U1.1 (CTG), U1.4 (GND), U1.6 (QSTRT), U1.9 (GND), U2.5 (GND), U2.21 (GND), U2.24 (GND), U4.4 (~CE), U4.5 (EN2), U4.8 (VSS), U4.17 (VSS), U5.3 (S2), U6.2 (VN); also elsewhere on the board
LSW: U2.7 (P0.02/AIN0); also elsewhere on the board
MOSI: U2.35 (P0.24); also elsewhere on the board
unnamed: BSW1.1 (A), R17.1
unnamed: F31.2, L31.1
unnamed: C11.2, J3.2, U5.1 (S1), U7.6 (VSS)
unnamed: J33.A5 (CC1), R36.2
unnamed: J33.B5 (CC2), R35.2
unnamed: Q1.1 (G), R15.2, R16.1
unnamed: C3.1, U2.11 (P0.00/XL1), Y1.2
unnamed: C4.1, U2.13 (P0.01/XL2), Y1.1
unnamed: R3.1, U4.16 (ISET)
unnamed: R4.1, U4.1 (TS)
unnamed: R7.2, U4.9 (~CHG)
unnamed: U5.6 (G1), U7.1 (OD)
unnamed: U5.4 (G2), U7.3 (OC)
unnamed: R11.2, U7.2 (CSI)
unnamed: C11.1, R10.2, U7.5 (VDD)
RDY/MCLR: J31.4, U2.22 (P0.07)
RST: J1.3 (~RST), RSW1.1, U2.26 (P0.18/~RESET)
RSW: U2.8 (P0.29/AIN5); also elsewhere on the board
SCL: J31.2, R6.2, U1.7 (SCL), U2.17 (P1.09); also elsewhere on the board
SDA: J31.3, R5.2, U1.8 (SDA), U2.15 (P0.05/AIN3)
SWDCLK: J1.4 (SWCLK), U2.39 (SWDCLK)
SWDIO: J1.2 (SWDIO), U2.37 (SWDIO)
SYSOFF: BSW1.2 (B), Q1.3 (D), U4.15 (SYSOFF)
VBUS: F31.1, J33.A4 (VBUS), J33.A9 (VBUS), J33.B4 (VBUS), J33.B9 (VBUS), U6.5 (VP)
VDD: C5.1, J1.1 (VCC), J31.5, L1.2, R5.1, R6.1, U2.19 (VDD); also elsewhere on the board
col1: U2.43 (P0.10/NFC2); also elsewhere on the board
col2: U2.41 (P0.09/NFC1); also elsewhere on the board
col3: U2.42 (P1.06); also elsewhere on the board
col4: U2.40 (P1.04); also elsewhere on the board
col5: U2.38 (P1.02); also elsewhere on the board
col6: U2.20 (P0.12); also elsewhere on the board
row2: U2.30 (P0.17); also elsewhere on the board
row3: U2.32 (P0.20); also elsewhere on the board
row4: U2.34 (P0.22); also elsewhere on the board
row5: U2.36 (P1.00); also elsewhere on the board

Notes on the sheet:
SYSOFF 1 (SW1 pos 1): Batt OFF SYSOFF 0 (SW1 pos 3): Batt ON
nRF52 module with peripherals
External DCCH inductor for DC-DC HV input mode
Trackpad FPC Connector
Programming header
Reset Switch
Pull-ups for i2c
Battery management
Matrix
OLED & Button
ESD input protection
TMR: (10 x 48 s/kOhm) * 47 kOhm = 22560s = 6.27h ILIM: 1550 AOhm / 1500 Ohm = 1.03 A = 1030 mA ISET: 890 AOhm / 2000 Ohm = 0.445 A = 445 mA EN1: 1, EN2: 0 = 500 mA MAX TS: 10 kOhm to GND = no OTP
USB Port
AND gate for ZMK soft poweroff feature
LED
Fuel Gauge
External LF crystal for lower idle power

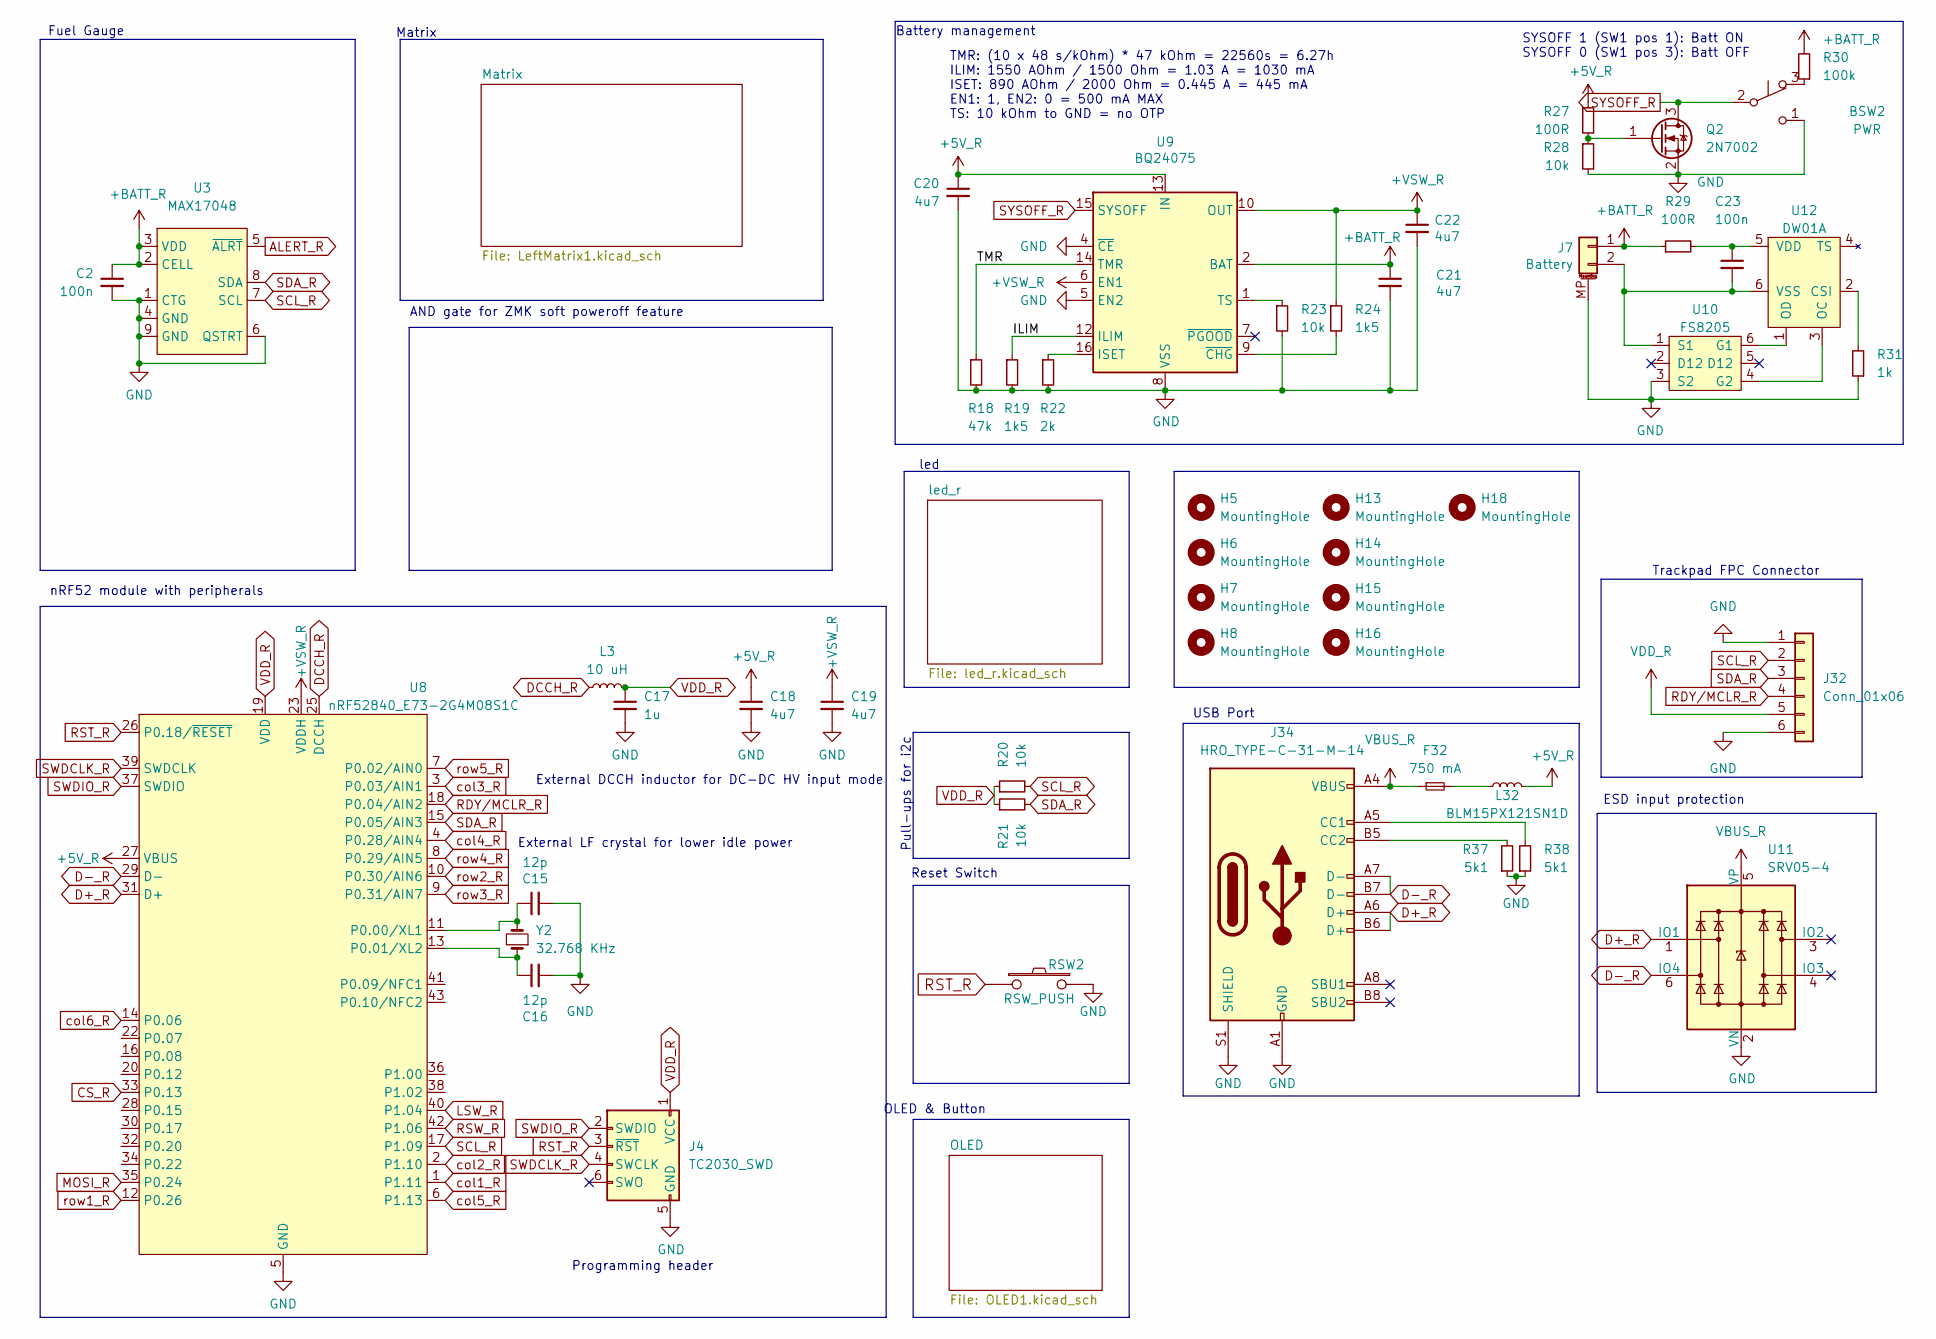
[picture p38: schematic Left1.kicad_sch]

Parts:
BSW2: PWR; SW_MSK12C02-HB
C2: 100n; C_0402_1005Metric; LCSC C307331
C15, C16: 12p; C_0402_1005Metric; LCSC C1547
C17: 1u; C_0402_1005Metric; LCSC C52923
C18, C19: 4u7; C_0402_1005Metric; LCSC C23733
C20, C21, C22: 4u7; C_0402_1005Metric
C23: 100n; C_0402_1005Metric
F32: 750 mA; Fuse_0603_1608Metric
H5, H6, H7, H8: MountingHole; SMD-1_SMTSO1620MTJ
H13, H14, H15, H16, H18: MountingHole; SMD_BD5.6-L5.6-W5.6-D3.6
J4: TC2030_SWD; CON_TC2030_outlined
J7: Battery; Molex_Pico-EZmate_78171-0002_1x02-1MP_P1.20mm_Vertical; LCSC C505023
J32: Conn_01x06; FPC-SMD_6P-P0.50_XUNPU_FPC-05F-6PH15
J34: HRO_TYPE-C-31-M-14; USB_C_Receptacle_HRO_TYPE-C-31-M-14
L3: 10 uH; L_0603_1608Metric; LCSC C92982
L32: BLM15PX121SN1D; L_0402_1005Metric
Q2: 2N7002; SOT-23
R18: 47k; R_0402_1005Metric
R19, R24: 1k5; R_0402_1005Metric
R20, R21: 10k; R_0402_1005Metric; LCSC C25744
R22: 2k; R_0402_1005Metric
R23, R28: 10k; R_0402_1005Metric
R27, R29: 100R; R_0402_1005Metric
R30: 100k; R_0402_1005Metric
R31: 1k; R_0402_1005Metric
R37, R38: 5k1; R_0402_1005Metric
RSW2: RSW_PUSH; SW-SMD_4P-L5.1-W5.1-P3.70-LS6.5-TL_H1.5
U3: MAX17048; DFN-8-1EP_2x2mm_P0.5mm_EP0.6x1.2mm; LCSC C2682616
U8: nRF52840_E73-2G4M08S1C; LCSC C356849
U9: BQ24075; VQFN-16-1EP_3x3mm_P0.5mm_EP1.6x1.6mm
U10: FS8205; SOT-23-6; LCSC C32254
U11: SRV05-4; SOT-23-6-routable; LCSC C7420376
U12: DW01A; SOT-23-6; LCSC C61503
Y2: 32.768 KHz; Crystal_SMD_2012-2Pin_2.0x1.2mm; LCSC C55208

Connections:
+5V_R: C18.1, C20.1, L32.2, R27.1, U8.27 (VBUS), U9.13 (IN)
+BATT_R: C2.1, C21.1, J7.1, R29.1, R30.2, U3.2 (CELL), U3.3 (VDD), U9.2 (BAT), U9.3 (BAT)
+VSW_R: C19.1, C22.1, R24.1, U8.23 (VDDH), U9.6 (EN1), U9.10 (OUT), U9.11 (OUT)
/Left1/ILIM: R19.1, U9.12 (ILIM)
/Left1/TMR: R18.1, U9.14 (TMR)
ALERT_R: U3.5 (~ALRT)
CS_R: U8.33 (P0.13); also elsewhere on the board
D+_R: J34.A6 (D+), J34.B6 (D+), U8.31 (D+), U11.1 (IO1)
D-_R: J34.A7 (D-), J34.B7 (D-), U8.29 (D-), U11.6 (IO4)
DCCH_R: L3.1, U8.25 (DCCH)
GND: BSW2.1 (C), C2.2, C15.2, C16.2, C17.2, C18.2, C19.2, C20.2, C21.2, C22.2, J4.5 (GND), J7.MP (MountPin), J32.1, J32.6, J34.A1 (GND), J34.A12 (GND), J34.B1 (GND), J34.B12 (GND), J34.S1 (SHIELD), Q2.2 (S), R18.2, R19.2, R22.2, R23.2, R28.2, R31.1, R37.1, R38.1, RSW2.2, U3.1 (CTG), U3.4 (GND), U3.6 (QSTRT), U3.9 (GND), U8.5 (GND), U8.21 (GND), U8.24 (GND), U9.4 (~CE), U9.5 (EN2), U9.8 (VSS), U9.17 (VSS), U10.3 (S2), U11.2 (VN); also elsewhere on the board
LSW_R: U8.40 (P1.04); also elsewhere on the board
MOSI_R: U8.35 (P0.24); also elsewhere on the board
unnamed: BSW2.3 (A), R30.1
unnamed: F32.2, L32.1
unnamed: C23.2, J7.2, U10.1 (S1), U12.6 (VSS)
unnamed: J34.A5 (CC1), R38.2
unnamed: J34.B5 (CC2), R37.2
unnamed: Q2.1 (G), R27.2, R28.1
unnamed: C15.1, U8.11 (P0.00/XL1), Y2.2
unnamed: C16.1, U8.13 (P0.01/XL2), Y2.1
unnamed: R22.1, U9.16 (ISET)
unnamed: R23.1, U9.1 (TS)
unnamed: R24.2, U9.9 (~CHG)
unnamed: U10.6 (G1), U12.1 (OD)
unnamed: U10.4 (G2), U12.3 (OC)
unnamed: R31.2, U12.2 (CSI)
unnamed: C23.1, R29.2, U12.5 (VDD)
RDY/MCLR_R: J32.4, U8.18 (P0.04/AIN2)
RST_R: J4.3 (~RST), RSW2.1, U8.26 (P0.18/~RESET)
RSW_R: U8.42 (P1.06); also elsewhere on the board
SCL_R: J32.2, R20.2, U3.7 (SCL), U8.17 (P1.09); also elsewhere on the board
SDA_R: J32.3, R21.2, U3.8 (SDA), U8.15 (P0.05/AIN3)
SWDCLK_R: J4.4 (SWCLK), U8.39 (SWDCLK)
SWDIO_R: J4.2 (SWDIO), U8.37 (SWDIO)
SYSOFF_R: BSW2.2 (B), Q2.3 (D), U9.15 (SYSOFF)
VBUS_R: F32.1, J34.A4 (VBUS), J34.A9 (VBUS), J34.B4 (VBUS), J34.B9 (VBUS), U11.5 (VP)
VDD_R: C17.1, J4.1 (VCC), J32.5, L3.2, R20.1, R21.1, U8.19 (VDD); also elsewhere on the board
col1_R: U8.1 (P1.11); also elsewhere on the board
col2_R: U8.2 (P1.10); also elsewhere on the board
col3_R: U8.3 (P0.03/AIN1); also elsewhere on the board
col4_R: U8.4 (P0.28/AIN4); also elsewhere on the board
col5_R: U8.6 (P1.13); also elsewhere on the board
col6_R: U8.14 (P0.06); also elsewhere on the board
row2_R: U8.10 (P0.30/AIN6); also elsewhere on the board
row3_R: U8.9 (P0.31/AIN7); also elsewhere on the board
row4_R: U8.8 (P0.29/AIN5); also elsewhere on the board
row5_R: U8.7 (P0.02/AIN0); also elsewhere on the board

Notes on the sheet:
SYSOFF 1 (SW1 pos 1): Batt ON SYSOFF 0 (SW1 pos 3): Batt OFF
nRF52 module with peripherals
External DCCH inductor for DC-DC HV input mode
Trackpad FPC Connector
Programming header
Reset Switch
Pull-ups for i2c
Battery management
Matrix
OLED & Button
ESD input protection
led
TMR: (10 x 48 s/kOhm) * 47 kOhm = 22560s = 6.27h ILIM: 1550 AOhm / 1500 Ohm = 1.03 A = 1030 mA ISET: 890 AOhm / 2000 Ohm = 0.445 A = 445 mA EN1: 1, EN2: 0 = 500 mA MAX TS: 10 kOhm to GND = no OTP
USB Port
AND gate for ZMK soft poweroff feature
Fuel Gauge
External LF crystal for lower idle power

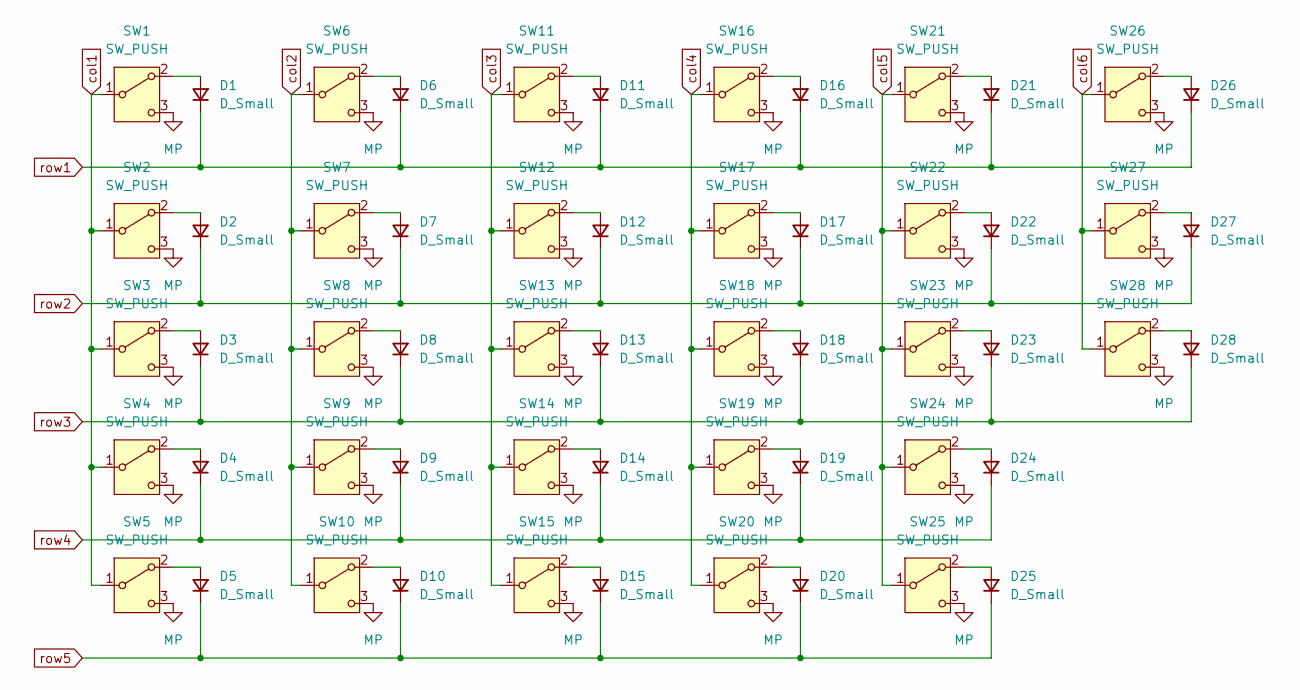
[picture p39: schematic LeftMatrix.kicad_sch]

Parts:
D1, D2, D3, D4, D5, D6, D7, D8, D9, D10, D11, D12, D13, D14, D15, D16, D17, D18, D19, D20, D21, D22, D23, D24, D25, D26, D27, D28: D_Small; D_SOD-123
SW1, SW2, SW3, SW4, SW5, SW6, SW7, SW8, SW9, SW10, SW11, SW12, SW13, SW14, SW15, SW16, SW17, SW18, SW19, SW20, SW21, SW22, SW23, SW24, SW25, SW26, SW27, SW28: SW_PUSH; HOB_CHOC_V1&V2

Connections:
unnamed: D2.2 (A), SW2.2 (A)
unnamed: D3.2 (A), SW3.2 (A)
unnamed: D4.2 (A), SW4.2 (A)
unnamed: D5.2 (A), SW5.2 (A)
unnamed: D6.2 (A), SW6.2 (A)
unnamed: D7.2 (A), SW7.2 (A)
unnamed: D8.2 (A), SW8.2 (A)
unnamed: D9.2 (A), SW9.2 (A)
unnamed: D10.2 (A), SW10.2 (A)
unnamed: D11.2 (A), SW11.2 (A)
unnamed: D12.2 (A), SW12.2 (A)
unnamed: D13.2 (A), SW13.2 (A)
unnamed: D14.2 (A), SW14.2 (A)
unnamed: D15.2 (A), SW15.2 (A)
unnamed: D16.2 (A), SW16.2 (A)
unnamed: D17.2 (A), SW17.2 (A)
unnamed: D18.2 (A), SW18.2 (A)
unnamed: D19.2 (A), SW19.2 (A)
unnamed: D20.2 (A), SW20.2 (A)
unnamed: D21.2 (A), SW21.2 (A)
unnamed: D22.2 (A), SW22.2 (A)
unnamed: D23.2 (A), SW23.2 (A)
unnamed: D24.2 (A), SW24.2 (A)
unnamed: D25.2 (A), SW25.2 (A)
unnamed: D26.2 (A), SW26.2 (A)
unnamed: D27.2 (A), SW27.2 (A)
unnamed: D28.2 (A), SW28.2 (A)
col1: SW1.1 (B), SW2.1 (B), SW3.1 (B), SW4.1 (B), SW5.1 (B); also elsewhere on the board
col2: SW6.1 (B), SW7.1 (B), SW8.1 (B), SW9.1 (B), SW10.1 (B); also elsewhere on the board
col3: SW11.1 (B), SW12.1 (B), SW13.1 (B), SW14.1 (B), SW15.1 (B); also elsewhere on the board
col4: SW16.1 (B), SW17.1 (B), SW18.1 (B), SW19.1 (B), SW20.1 (B); also elsewhere on the board
col5: SW21.1 (B), SW22.1 (B), SW23.1 (B), SW24.1 (B), SW25.1 (B); also elsewhere on the board
col6: SW26.1 (B), SW27.1 (B), SW28.1 (B); also elsewhere on the board
row2: D2.1 (K), D7.1 (K), D12.1 (K), D17.1 (K), D22.1 (K), D27.1 (K); also elsewhere on the board
row3: D3.1 (K), D8.1 (K), D13.1 (K), D18.1 (K), D23.1 (K), D28.1 (K); also elsewhere on the board
row4: D4.1 (K), D9.1 (K), D14.1 (K), D19.1 (K), D24.1 (K); also elsewhere on the board
row5: D5.1 (K), D10.1 (K), D15.1 (K), D20.1 (K), D25.1 (K); also elsewhere on the board

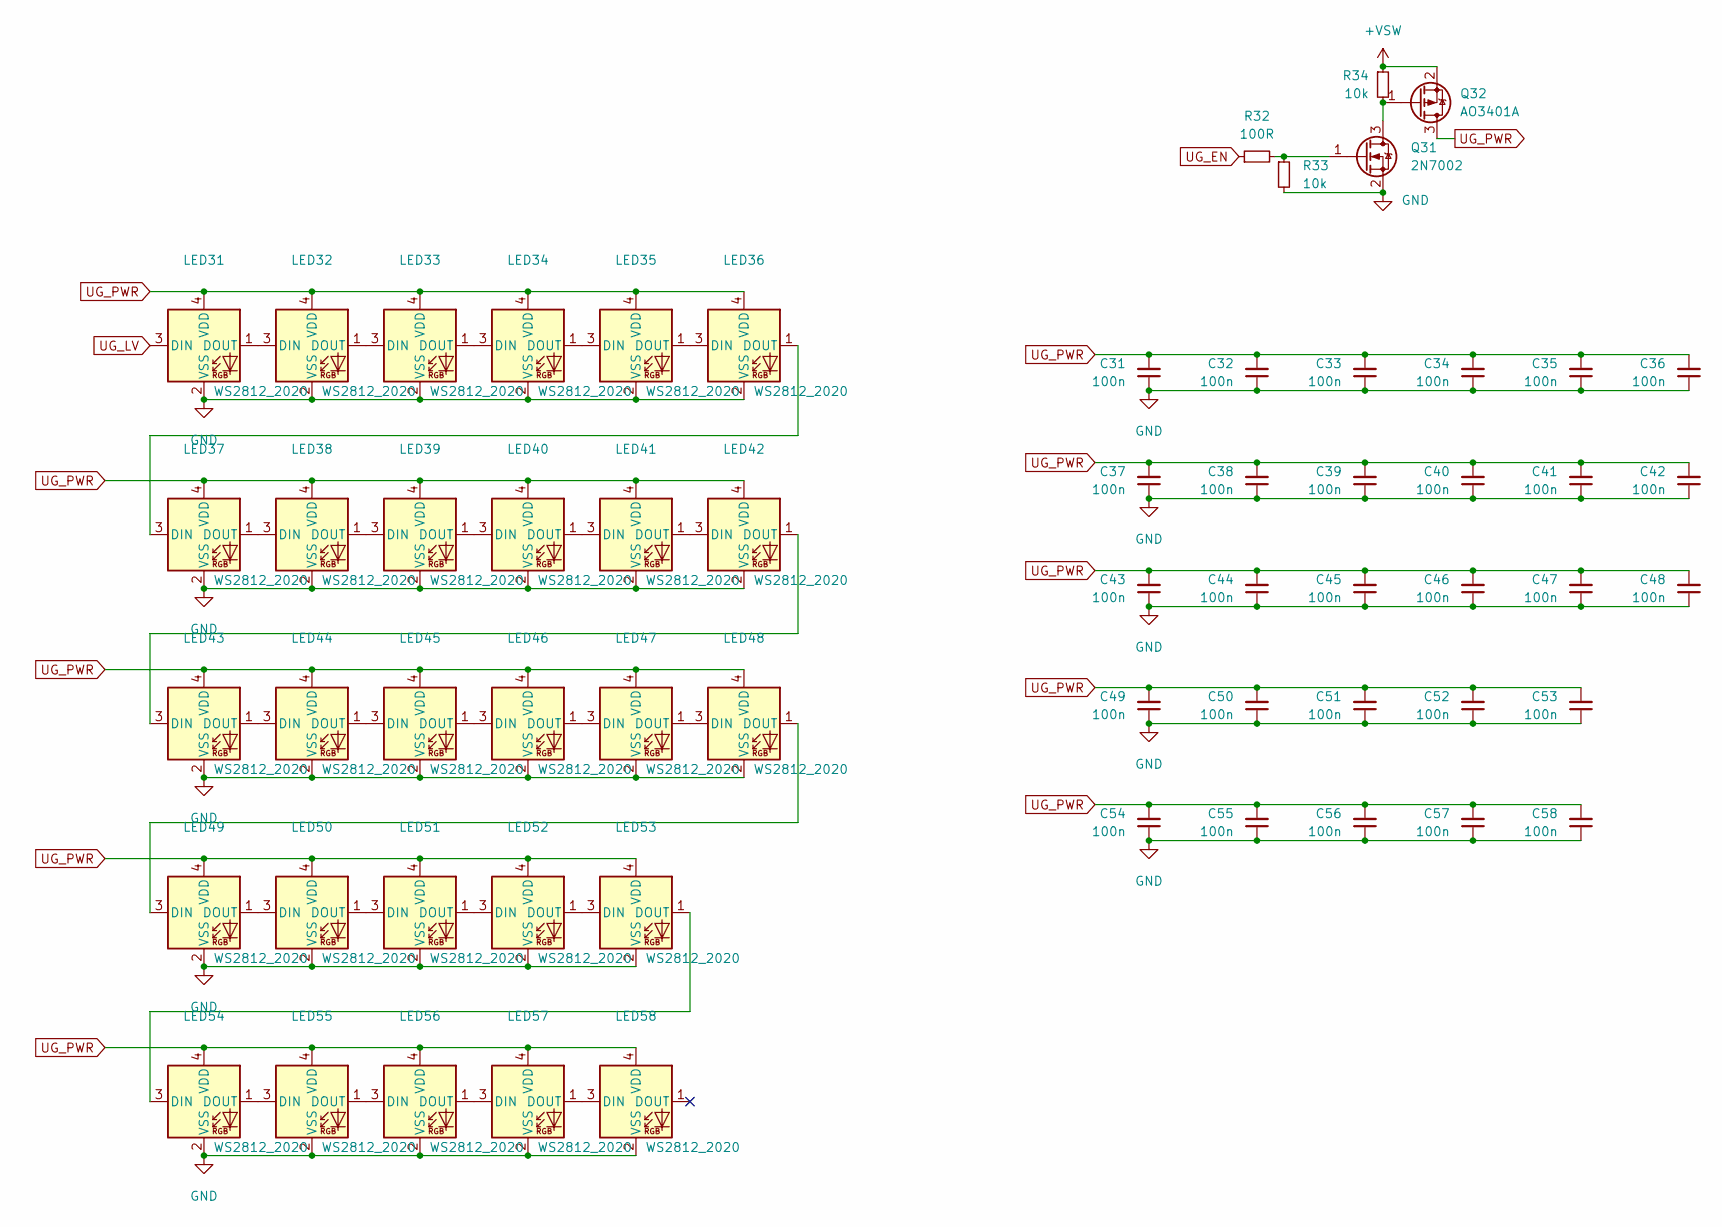
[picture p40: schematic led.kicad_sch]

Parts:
C31, C32, C33, C34, C35, C36, C37, C38, C39, C40, C41, C42, C43, C44, C45, C46, C47, C48, C49, C50, C51, C52, C53, C54, C55, C56, C57, C58: 100n; C_0402_1005Metric
LED31, LED32, LED33, LED34, LED35, LED36, LED37, LED38, LED39, LED40, LED41, LED42, LED43, LED44, LED45, LED46, LED47, LED48, LED49, LED50, LED51, LED52, LED53, LED54, LED55, LED56, LED57, LED58: WS2812_2020; YS-SK6812MINI-E
Q31: 2N7002; SOT-23
Q32: AO3401A; SOT-23
R32: 100R; R_0402_1005Metric
R33, R34: 10k; R_0402_1005Metric

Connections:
+VSW: Q32.2 (S), R34.1; also elsewhere on the board
GND: C31.1, C32.1, C33.1, C34.1, C35.1, C36.1, C37.1, C38.1, C39.1, C40.1, C41.1, C42.1, C43.1, C44.1, C45.1, C46.1, C47.1, C48.1, C49.1, C50.1, C51.1, C52.1, C53.1, C54.1, C55.1, C56.1, C57.1, C58.1, LED31.2 (VSS), LED32.2 (VSS), LED33.2 (VSS), LED34.2 (VSS), LED35.2 (VSS), LED36.2 (VSS), LED37.2 (VSS), LED38.2 (VSS), LED39.2 (VSS), LED40.2 (VSS), LED41.2 (VSS), LED42.2 (VSS), LED43.2 (VSS), LED44.2 (VSS), LED45.2 (VSS), LED46.2 (VSS), LED47.2 (VSS), LED48.2 (VSS), LED49.2 (VSS), LED50.2 (VSS), LED51.2 (VSS), LED52.2 (VSS), LED53.2 (VSS), LED54.2 (VSS), LED55.2 (VSS), LED56.2 (VSS), LED57.2 (VSS), LED58.2 (VSS), Q31.2 (S), R33.2; also elsewhere on the board
unnamed: LED31.1 (DOUT), LED32.3 (DIN)
unnamed: LED32.1 (DOUT), LED33.3 (DIN)
unnamed: LED33.1 (DOUT), LED34.3 (DIN)
unnamed: LED34.1 (DOUT), LED35.3 (DIN)
unnamed: LED35.1 (DOUT), LED36.3 (DIN)
unnamed: LED36.1 (DOUT), LED37.3 (DIN)
unnamed: LED37.1 (DOUT), LED38.3 (DIN)
unnamed: LED38.1 (DOUT), LED39.3 (DIN)
unnamed: LED39.1 (DOUT), LED40.3 (DIN)
unnamed: LED40.1 (DOUT), LED41.3 (DIN)
unnamed: LED41.1 (DOUT), LED42.3 (DIN)
unnamed: LED42.1 (DOUT), LED43.3 (DIN)
unnamed: LED43.1 (DOUT), LED44.3 (DIN)
unnamed: LED44.1 (DOUT), LED45.3 (DIN)
unnamed: LED45.1 (DOUT), LED46.3 (DIN)
unnamed: LED46.1 (DOUT), LED47.3 (DIN)
unnamed: LED47.1 (DOUT), LED48.3 (DIN)
unnamed: LED48.1 (DOUT), LED49.3 (DIN)
unnamed: LED49.1 (DOUT), LED50.3 (DIN)
unnamed: LED50.1 (DOUT), LED51.3 (DIN)
unnamed: LED51.1 (DOUT), LED52.3 (DIN)
unnamed: LED52.1 (DOUT), LED53.3 (DIN)
unnamed: LED53.1 (DOUT), LED54.3 (DIN)
unnamed: LED54.1 (DOUT), LED55.3 (DIN)
unnamed: LED55.1 (DOUT), LED56.3 (DIN)
unnamed: LED56.1 (DOUT), LED57.3 (DIN)
unnamed: LED57.1 (DOUT), LED58.3 (DIN)
unnamed: Q31.3 (D), Q32.1 (G), R34.2
unnamed: Q31.1 (G), R32.2, R33.1
UG_EN: R32.1
UG_LV: LED31.3 (DIN)
UG_PWR: C31.2, C32.2, C33.2, C34.2, C35.2, C36.2, C37.2, C38.2, C39.2, C40.2, C41.2, C42.2, C43.2, C44.2, C45.2, C46.2, C47.2, C48.2, C49.2, C50.2, C51.2, C52.2, C53.2, C54.2, C55.2, C56.2, C57.2, C58.2, LED31.4 (VDD), LED32.4 (VDD), LED33.4 (VDD), LED34.4 (VDD), LED35.4 (VDD), LED36.4 (VDD), LED37.4 (VDD), LED38.4 (VDD), LED39.4 (VDD), LED40.4 (VDD), LED41.4 (VDD), LED42.4 (VDD), LED43.4 (VDD), LED44.4 (VDD), LED45.4 (VDD), LED46.4 (VDD), LED47.4 (VDD), LED48.4 (VDD), LED49.4 (VDD), LED50.4 (VDD), LED51.4 (VDD), LED52.4 (VDD), LED53.4 (VDD), LED54.4 (VDD), LED55.4 (VDD), LED56.4 (VDD), LED57.4 (VDD), LED58.4 (VDD), Q32.3 (D)

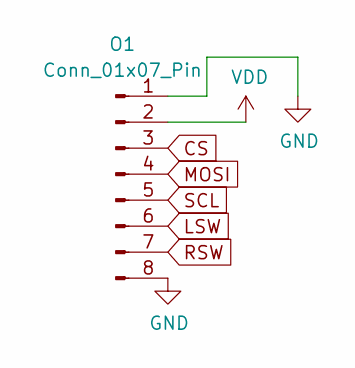
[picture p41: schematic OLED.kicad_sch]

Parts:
O1: Conn_01x07_Pin; FPC-SMD_8P-P0.50_XUNPU_FPC-05F-8PH15

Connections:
CS: O1.3; also elsewhere on the board
GND: O1.1, O1.8; also elsewhere on the board
LSW: O1.6; also elsewhere on the board
MOSI: O1.4; also elsewhere on the board
RSW: O1.7; also elsewhere on the board
SCL: O1.5; also elsewhere on the board
VDD: O1.2; also elsewhere on the board

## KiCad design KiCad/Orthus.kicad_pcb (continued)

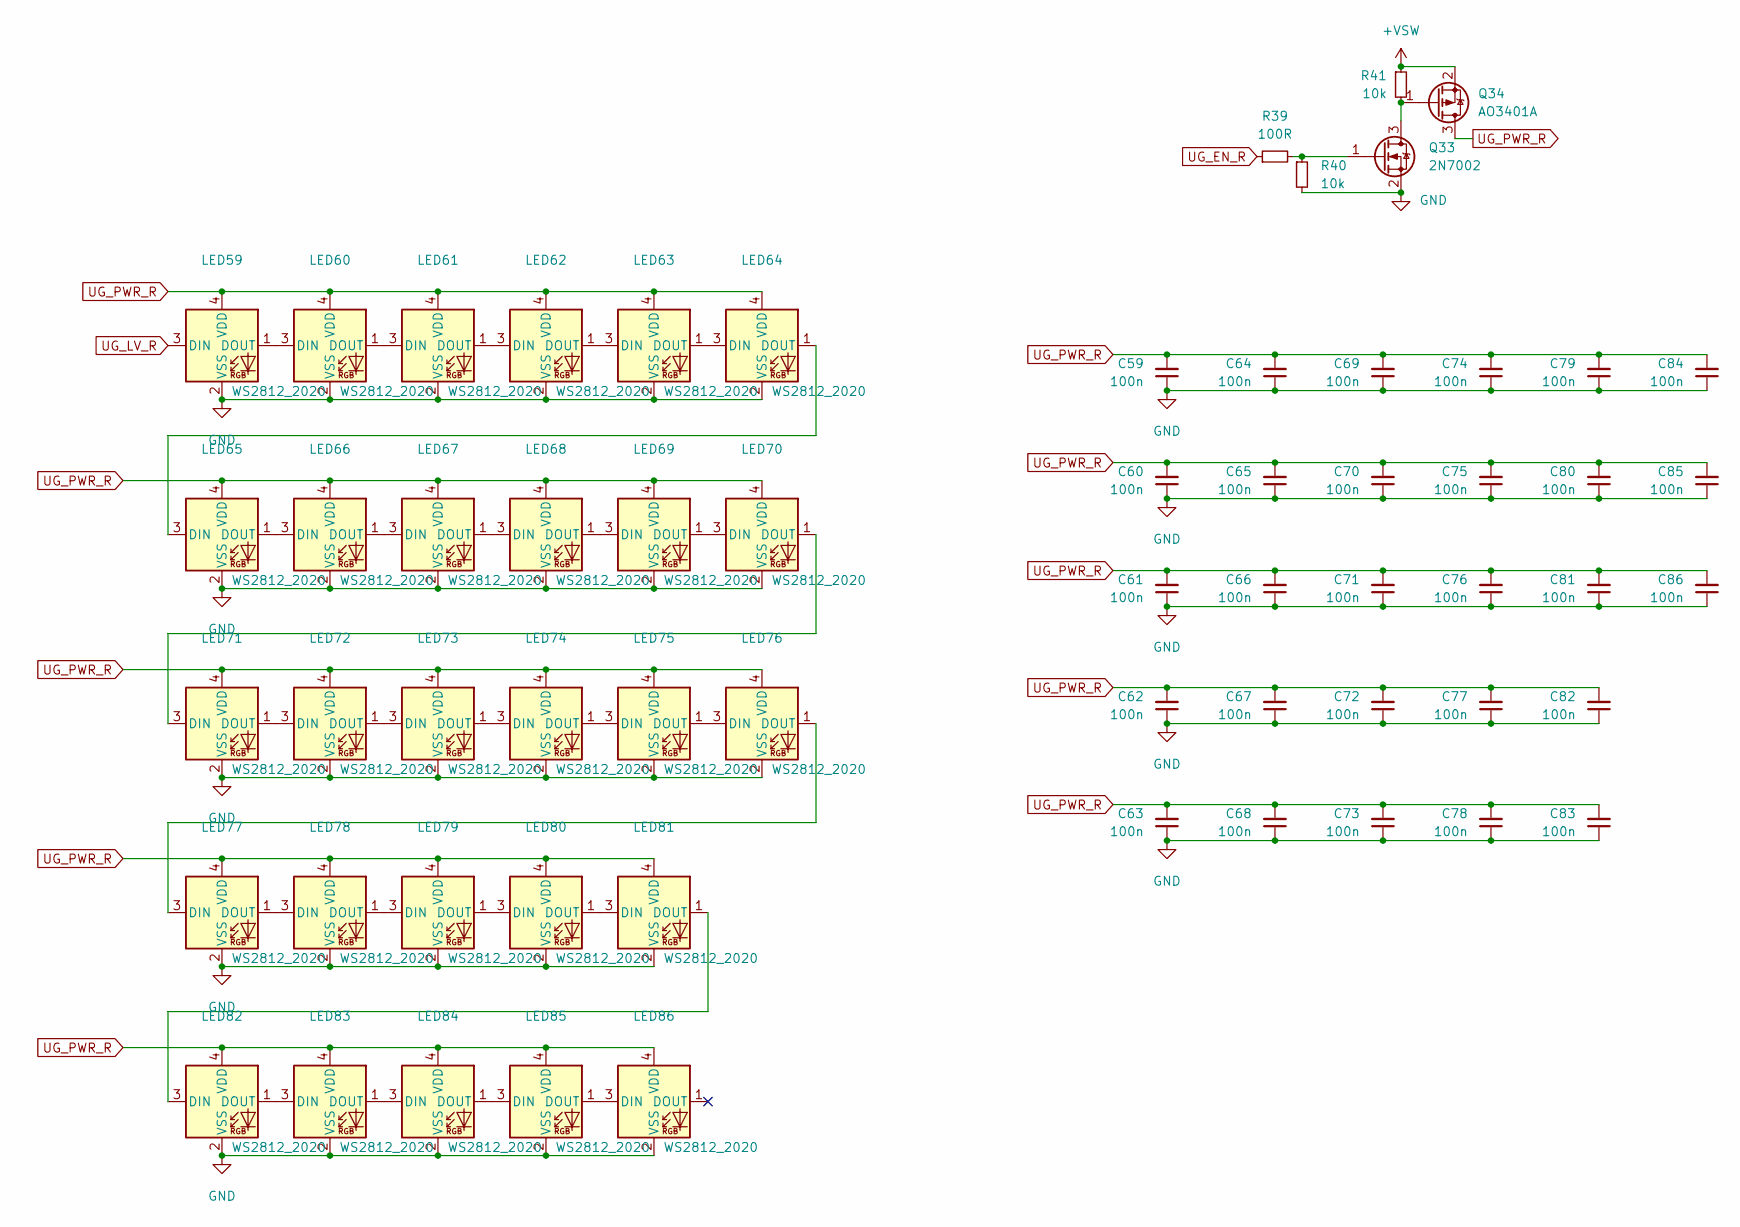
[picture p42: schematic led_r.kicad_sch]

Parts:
C59, C60, C61, C62, C63, C64, C65, C66, C67, C68, C69, C70, C71, C72, C73, C74, C75, C76, C77, C78, C79, C80, C81, C82, C83, C84, C85, C86: 100n; C_0402_1005Metric
LED59, LED60, LED61, LED62, LED63, LED64, LED65, LED66, LED67, LED68, LED69, LED70, LED71, LED72, LED73, LED74, LED75, LED76, LED77, LED78, LED79, LED80, LED81, LED82, LED83, LED84, LED85, LED86: WS2812_2020; YS-SK6812MINI-E
Q33: 2N7002; SOT-23
Q34: AO3401A; SOT-23
R39: 100R; R_0402_1005Metric
R40, R41: 10k; R_0402_1005Metric

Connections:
+VSW: Q34.2 (S), R41.1; also elsewhere on the board
GND: C59.1, C60.1, C61.1, C62.1, C63.1, C64.1, C65.1, C66.1, C67.1, C68.1, C69.1, C70.1, C71.1, C72.1, C73.1, C74.1, C75.1, C76.1, C77.1, C78.1, C79.1, C80.1, C81.1, C82.1, C83.1, C84.1, C85.1, C86.1, LED59.2 (VSS), LED60.2 (VSS), LED61.2 (VSS), LED62.2 (VSS), LED63.2 (VSS), LED64.2 (VSS), LED65.2 (VSS), LED66.2 (VSS), LED67.2 (VSS), LED68.2 (VSS), LED69.2 (VSS), LED70.2 (VSS), LED71.2 (VSS), LED72.2 (VSS), LED73.2 (VSS), LED74.2 (VSS), LED75.2 (VSS), LED76.2 (VSS), LED77.2 (VSS), LED78.2 (VSS), LED79.2 (VSS), LED80.2 (VSS), LED81.2 (VSS), LED82.2 (VSS), LED83.2 (VSS), LED84.2 (VSS), LED85.2 (VSS), LED86.2 (VSS), Q33.2 (S), R40.2; also elsewhere on the board
unnamed: LED59.1 (DOUT), LED60.3 (DIN)
unnamed: LED60.1 (DOUT), LED61.3 (DIN)
unnamed: LED61.1 (DOUT), LED62.3 (DIN)
unnamed: LED62.1 (DOUT), LED63.3 (DIN)
unnamed: LED63.1 (DOUT), LED64.3 (DIN)
unnamed: LED64.1 (DOUT), LED65.3 (DIN)
unnamed: LED65.1 (DOUT), LED66.3 (DIN)
unnamed: LED66.1 (DOUT), LED67.3 (DIN)
unnamed: LED67.1 (DOUT), LED68.3 (DIN)
unnamed: LED68.1 (DOUT), LED69.3 (DIN)
unnamed: LED69.1 (DOUT), LED70.3 (DIN)
unnamed: LED70.1 (DOUT), LED71.3 (DIN)
unnamed: LED71.1 (DOUT), LED72.3 (DIN)
unnamed: LED72.1 (DOUT), LED73.3 (DIN)
unnamed: LED73.1 (DOUT), LED74.3 (DIN)
unnamed: LED74.1 (DOUT), LED75.3 (DIN)
unnamed: LED75.1 (DOUT), LED76.3 (DIN)
unnamed: LED76.1 (DOUT), LED77.3 (DIN)
unnamed: LED77.1 (DOUT), LED78.3 (DIN)
unnamed: LED78.1 (DOUT), LED79.3 (DIN)
unnamed: LED79.1 (DOUT), LED80.3 (DIN)
unnamed: LED80.1 (DOUT), LED81.3 (DIN)
unnamed: LED81.1 (DOUT), LED82.3 (DIN)
unnamed: LED82.1 (DOUT), LED83.3 (DIN)
unnamed: LED83.1 (DOUT), LED84.3 (DIN)
unnamed: LED84.1 (DOUT), LED85.3 (DIN)
unnamed: LED85.1 (DOUT), LED86.3 (DIN)
unnamed: Q33.3 (D), Q34.1 (G), R41.2
unnamed: Q33.1 (G), R39.2, R40.1
UG_EN_R: R39.1
UG_LV_R: LED59.3 (DIN)
UG_PWR_R: C59.2, C60.2, C61.2, C62.2, C63.2, C64.2, C65.2, C66.2, C67.2, C68.2, C69.2, C70.2, C71.2, C72.2, C73.2, C74.2, C75.2, C76.2, C77.2, C78.2, C79.2, C80.2, C81.2, C82.2, C83.2, C84.2, C85.2, C86.2, LED59.4 (VDD), LED60.4 (VDD), LED61.4 (VDD), LED62.4 (VDD), LED63.4 (VDD), LED64.4 (VDD), LED65.4 (VDD), LED66.4 (VDD), LED67.4 (VDD), LED68.4 (VDD), LED69.4 (VDD), LED70.4 (VDD), LED71.4 (VDD), LED72.4 (VDD), LED73.4 (VDD), LED74.4 (VDD), LED75.4 (VDD), LED76.4 (VDD), LED77.4 (VDD), LED78.4 (VDD), LED79.4 (VDD), LED80.4 (VDD), LED81.4 (VDD), LED82.4 (VDD), LED83.4 (VDD), LED84.4 (VDD), LED85.4 (VDD), LED86.4 (VDD), Q34.3 (D)

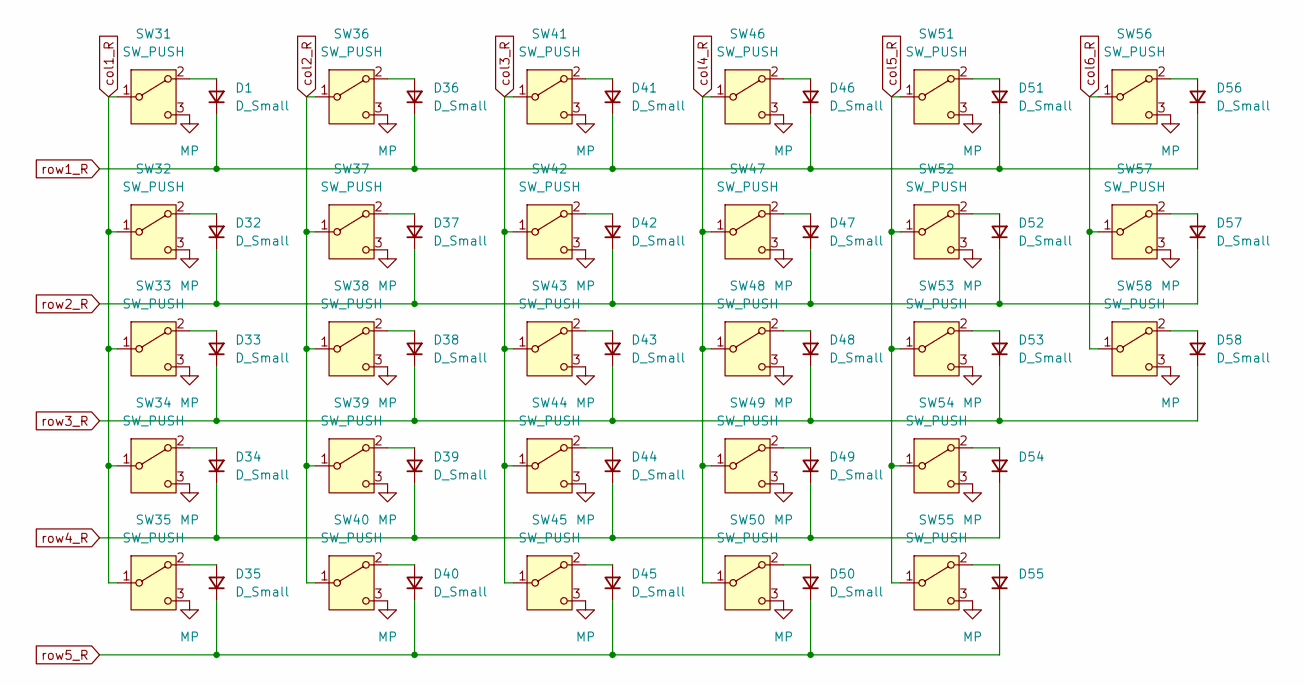
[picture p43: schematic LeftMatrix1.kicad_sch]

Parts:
D1, D32, D33, D34, D35, D36, D37, D38, D39, D40, D41, D42, D43, D44, D45, D46, D47, D48, D49, D50, D51, D52, D53, D54, D55, D56, D57, D58: D_Small; D_SOD-123
SW31, SW32, SW33, SW34, SW35, SW36, SW37, SW38, SW39, SW40, SW41, SW42, SW43, SW44, SW45, SW46, SW47, SW48, SW49, SW50, SW51, SW52, SW53, SW54, SW55, SW56, SW57, SW58: SW_PUSH; HOB_CHOC_V1&V2

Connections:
unnamed: D32.2 (A), SW32.2 (A)
unnamed: D33.2 (A), SW33.2 (A)
unnamed: D34.2 (A), SW34.2 (A)
unnamed: D35.2 (A), SW35.2 (A)
unnamed: D36.2 (A), SW36.2 (A)
unnamed: D37.2 (A), SW37.2 (A)
unnamed: D38.2 (A), SW38.2 (A)
unnamed: D39.2 (A), SW39.2 (A)
unnamed: D40.2 (A), SW40.2 (A)
unnamed: D41.2 (A), SW41.2 (A)
unnamed: D42.2 (A), SW42.2 (A)
unnamed: D43.2 (A), SW43.2 (A)
unnamed: D44.2 (A), SW44.2 (A)
unnamed: D45.2 (A), SW45.2 (A)
unnamed: D46.2 (A), SW46.2 (A)
unnamed: D47.2 (A), SW47.2 (A)
unnamed: D48.2 (A), SW48.2 (A)
unnamed: D49.2 (A), SW49.2 (A)
unnamed: D50.2 (A), SW50.2 (A)
unnamed: D51.2 (A), SW51.2 (A)
unnamed: D52.2 (A), SW52.2 (A)
unnamed: D53.2 (A), SW53.2 (A)
unnamed: D54.2 (A), SW54.2 (A)
unnamed: D55.2 (A), SW55.2 (A)
unnamed: D56.2 (A), SW56.2 (A)
unnamed: D57.2 (A), SW57.2 (A)
unnamed: D58.2 (A), SW58.2 (A)
col1_R: SW31.1 (B), SW32.1 (B), SW33.1 (B), SW34.1 (B), SW35.1 (B); also elsewhere on the board
col2_R: SW36.1 (B), SW37.1 (B), SW38.1 (B), SW39.1 (B), SW40.1 (B); also elsewhere on the board
col3_R: SW41.1 (B), SW42.1 (B), SW43.1 (B), SW44.1 (B), SW45.1 (B); also elsewhere on the board
col4_R: SW46.1 (B), SW47.1 (B), SW48.1 (B), SW49.1 (B), SW50.1 (B); also elsewhere on the board
col5_R: SW51.1 (B), SW52.1 (B), SW53.1 (B), SW54.1 (B), SW55.1 (B); also elsewhere on the board
col6_R: SW56.1 (B), SW57.1 (B), SW58.1 (B); also elsewhere on the board
row2_R: D32.1 (K), D37.1 (K), D42.1 (K), D47.1 (K), D52.1 (K), D57.1 (K); also elsewhere on the board
row3_R: D33.1 (K), D38.1 (K), D43.1 (K), D48.1 (K), D53.1 (K), D58.1 (K); also elsewhere on the board
row4_R: D34.1 (K), D39.1 (K), D44.1 (K), D49.1 (K), D54.1 (K); also elsewhere on the board
row5_R: D35.1 (K), D40.1 (K), D45.1 (K), D50.1 (K), D55.1 (K); also elsewhere on the board

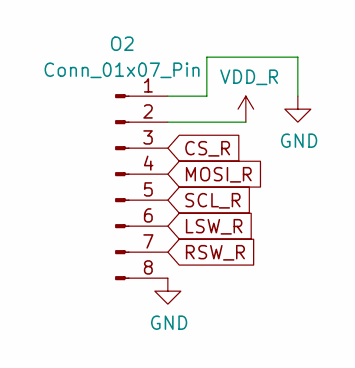
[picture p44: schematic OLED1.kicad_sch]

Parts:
O2: Conn_01x07_Pin; FPC-SMD_8P-P0.50_XUNPU_FPC-05F-8PH15

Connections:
CS_R: O2.3; also elsewhere on the board
GND: O2.1, O2.8; also elsewhere on the board
LSW_R: O2.6; also elsewhere on the board
MOSI_R: O2.4; also elsewhere on the board
RSW_R: O2.7; also elsewhere on the board
SCL_R: O2.5; also elsewhere on the board
VDD_R: O2.2; also elsewhere on the board

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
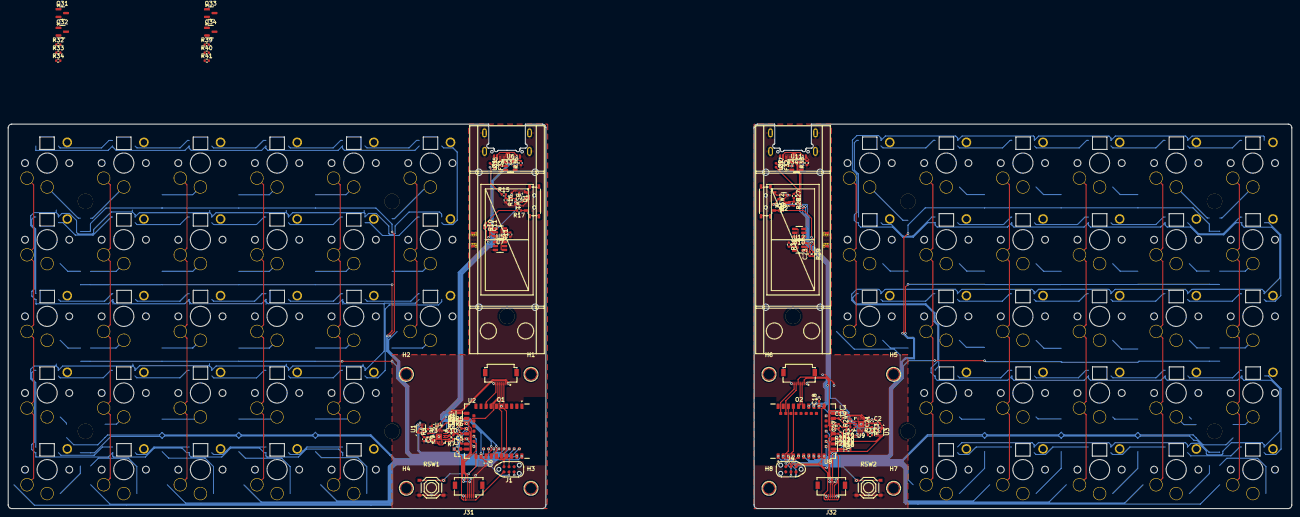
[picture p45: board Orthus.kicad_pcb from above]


Board: 2 copper layers, 319.0 x 95.6 mm, 336 parts (236 on the bottom side), 211 nets.

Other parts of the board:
D31: D_Small; D_SOD-123

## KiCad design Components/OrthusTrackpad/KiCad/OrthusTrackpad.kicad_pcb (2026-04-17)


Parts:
C1, C3, C5: 100pF; C_0402_1005Metric
C2, C4, C6: 2.2uF; C_0402_1005Metric
C7: 100nF; C_0402_1005Metric
H1, H2, H3, H4: MountingHole; SMD-1_SMTSO1620MTJ
J1: Conn_01x06; FPC-SMD_6P-P0.50_XUNPU_FPC-05F-6PH15
R1, R2, R3: 4.7k; R_0603_1608Metric
U1: IQS7211E001QNR; UQFN-20_L3.0-W3.0-P0.40-BL-EP1.7; LCSC Part C20179547

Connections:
GND: C1.2, C2.1, C3.1, C4.1, C5.1, C6.1, C7.2, J1.1, J1.6, U1.3 (VSS), U1.21 (EP)
RDY/MCLR: C7.1, J1.4, R1.2, U1.20 (RDY/MCLR(VPP))
RX0: U1.5 (RX0/TX0)
RX1: U1.6 (RX1/TX1)
RX2: U1.7 (RX2/TX2)
RX3: U1.8 (RX3/TX3)
RX4: U1.9 (RX4/TX4)
RX5: U1.10 (RX5/TX5)
RX6: U1.11 (RX6/TX6)
RX7: U1.12 (RX7/TX7)
SCL: J1.2, R2.2, U1.18 (SCL)
SDA: J1.3, R3.2, U1.19 (SDA)
TX8: U1.13 (TX8)
TX9: U1.14 (TX9)
TX10: U1.15 (TX10)
TX11: U1.16 (TX11)
TX12: U1.17 (TX12)
VDD: C5.2, C6.2, J1.5, R1.1, R2.1, R3.1, U1.1 (VDD)
VREGA: C1.1, C2.2, U1.4 (VREGA)
VREGD: C3.2, C4.2, U1.2 (VREGD)



Board: 2 copper layers, 36.4 x 36.4 mm, 16 parts (16 on the bottom side), 7 nets.

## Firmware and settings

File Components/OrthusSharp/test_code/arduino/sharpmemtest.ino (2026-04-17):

/*********************************************************************
This is an example sketch for our Monochrome SHARP Memory Displays

  Pick one up today in the adafruit shop!
  ------> http://www.adafruit.com/products/1393

These displays use SPI to communicate, 3 pins are required to
interface

Adafruit invests time and resources providing this open source code,
please support Adafruit and open-source hardware by purchasing
products from Adafruit!

Written by Limor Fried/Ladyada  for Adafruit Industries.
BSD license, check license.txt for more information
All text above, must be included in any redistribution
*********************************************************************/

#include <Adafruit_GFX.h>
#include <Adafruit_SharpMem.h>

// Tested using nrfmicro edit your pin according to your controller

// any pins can be used
#define SHARP_SCK  45 //CLK P1_13
#define SHARP_MOSI 43 //DI P1_10
#define SHARP_SS   10//CS P0_10

// nrfmicro pin (32*pin)+gpio

// Set the size of the display here, e.g. 144x168!
Adafruit_SharpMem display(SHARP_SCK, SHARP_MOSI, SHARP_SS, 160, 68);
// The currently-available SHARP Memory Display (144x168 pixels)
// requires > 4K of microcontroller RAM; it WILL NOT WORK on Arduino Uno
// or other <4K "classic" devices!  The original display (96x96 pixels)
// does work there, but is no longer produced.

#define BLACK 0
#define WHITE 1

int minorHalfSize; // 1/2 of lesser of display width or height

void setup(void)
{
  Serial.begin(9600);
  Serial.println("Hello!");

  // start & clear the display
  display.begin();
  display.clearDisplay();

  // Several shapes are drawn centered on the screen.  Calculate 1/2 of
  // lesser of display width or height, this is used repeatedly later.
  minorHalfSize = min(display.width(), display.height()) / 2;

  // draw a single pixel
  display.drawPixel(10, 10, BLACK);
  display.refresh();
  delay(500);
  display.clearDisplay();

  // draw many lines
  testdrawline();
  delay(500);
  display.clearDisplay();

  // draw rectangles
  testdrawrect();
  delay(500);
  display.clearDisplay();

  // draw multiple rectangles
  testfillrect();
  display.refresh();
  delay(500);
  display.clearDisplay();

  // draw a circle, 10 pixel radius
  display.fillCircle(display.width()/2, display.height()/2, 10, BLACK);
  display.refresh();
  delay(500);
  display.clearDisplay();

  testdrawroundrect();
  display.refresh();
  delay(500);
  display.clearDisplay();

  testfillroundrect();
  display.refresh();
  delay(500);
  display.clearDisplay();

  testdrawtriangle();
  display.refresh();
  delay(500);
  display.clearDisplay();

  testfilltriangle();
  display.refresh();
  delay(500);
  display.clearDisplay();

  testdrawchar();
  display.refresh();
  for(int i=0; i<4; i++) {
    display.refresh();
    delay(500);
  }
}

void loop(void) 
{
  for(int i=0; i<4; i++) {
    display.setRotation(i);
    display.clearDisplay();
    // text display tests
    display.setTextSize(1);
    display.setTextColor(BLACK);
    display.setCursor(0,0);
    display.println("Hello, world!");
    display.setTextColor(WHITE, BLACK); // inverted text
    display.println(3.141592);
    display.setTextSize(2);
    display.setTextColor(BLACK);
    display.print("0x"); display.println(0xDEADBEEF, HEX);
    // Screen must be refreshed at least once per second
    for(int j=0; j<4; j++) {
      display.refresh();
      delay(500); // 1/2 sec delay
    } // x4 = 2 second pause between rotations
  }
}

///

void testdrawline() {
  for (int i=0; i<display.width(); i+=4) {
    display.drawLine(0, 0, i, display.height()-1, BLACK);
    display.refresh();
  }
  for (int i=0; i<display.height(); i+=4) {
    display.drawLine(0, 0, display.width()-1, i, BLACK);
    display.refresh();
  }
  delay(250);

  display.clearDisplay();
  for (int i=0; i<display.width(); i+=4) {
    display.drawLine(0, display.height()-1, i, 0, BLACK);
    display.refresh();
  }
  for (int i=display.height()-1; i>=0; i-=4) {
    display.drawLine(0, display.height()-1, display.width()-1, i, BLACK);
    display.refresh();
  }
  delay(250);

  display.clearDisplay();
  for (int i=display.width()-1; i>=0; i-=4) {
    display.drawLine(display.width()-1, display.height()-1, i, 0, BLACK);
    display.refresh();
  }
  for (int i=display.height()-1; i>=0; i-=4) {
    display.drawLine(display.width()-1, display.height()-1, 0, i, BLACK);
    display.refresh();
  }
  delay(250);

  display.clearDisplay();
  for (int i=0; i<display.height(); i+=4) {
    display.drawLine(display.width()-1, 0, 0, i, BLACK);
    display.refresh();
  }
  for (int i=0; i<display.width(); i+=4) {
    display.drawLine(display.width()-1, 0, i, display.height()-1, BLACK);
    display.refresh();
  }
  delay(250);
}

void testdrawrect(void) {
  for (int i=0; i<minorHalfSize; i+=2) {
    display.drawRect(i, i, display.width()-2*i, display.height()-2*i, BLACK);
    display.refresh();
  }
}

void testfillrect(void) {
  uint8_t color = BLACK;
  for (int i=0; i<minorHalfSize; i+=3) {
    // alternate colors
    display.fillRect(i, i, display.width()-i*2, display.height()-i*2, color&1);
    display.refresh();
    color++;
  }
}

void testdrawroundrect(void) {
  for (int i=0; i<minorHalfSize/2; i+=2) {
    display.drawRoundRect(i, i, display.width()-2*i, display.height()-2*i, minorHalfSize/2, BLACK);
    display.refresh();
  }
}

void testfillroundrect(void) {
  uint8_t color = BLACK;
  for (int i=0; i<minorHalfSize/2; i+=2) {
    display.fillRoundRect(i, i, display.width()-2*i, display.height()-2*i, minorHalfSize/2, color&1);
    display.refresh();
    color++;
  }
}

void testdrawtriangle(void) {
  for (int i=0; i<minorHalfSize; i+=5) {
    display.drawTriangle(display.width()/2, display.height()/2-i,
                     display.width()/2-i, display.height()/2+i,
                     display.width()/2+i, display.height()/2+i, BLACK);
    display.refresh();
  }
}

void testfilltriangle(void) {
  uint8_t color = BLACK;
  for (int i=minorHalfSize; i>0; i-=5) {
    display.fillTriangle(display.width()/2  , display.height()/2-i,
                         display.width()/2-i, display.height()/2+i,
                         display.width()/2+i, display.height()/2+i, color & 1);
    display.refresh();
    color++;
  }
}

void testdrawchar(void) {
  display.setTextSize(1);
  display.setTextColor(BLACK);
  display.setCursor(0,0);
  display.cp437(true);

  for (int i=0; i < 256; i++) {
    if (i == '\n') continue;
    display.write(i);
  }
  display.refresh();
}

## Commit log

2026-04-17 init commit
    [AltarCap v2.step, AltarCap v3.step, BOM-OrthusTrackpad.csv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]
2026-04-30 Relicense to CC BY-NC 4.0
    Switch from MIT to Creative Commons Attribution-NonCommercial 4.0
    to permit non-commercial use, modification, and forks while
    disallowing commercial exploitation. OrthusSharp third-party
    component retains its original license.
